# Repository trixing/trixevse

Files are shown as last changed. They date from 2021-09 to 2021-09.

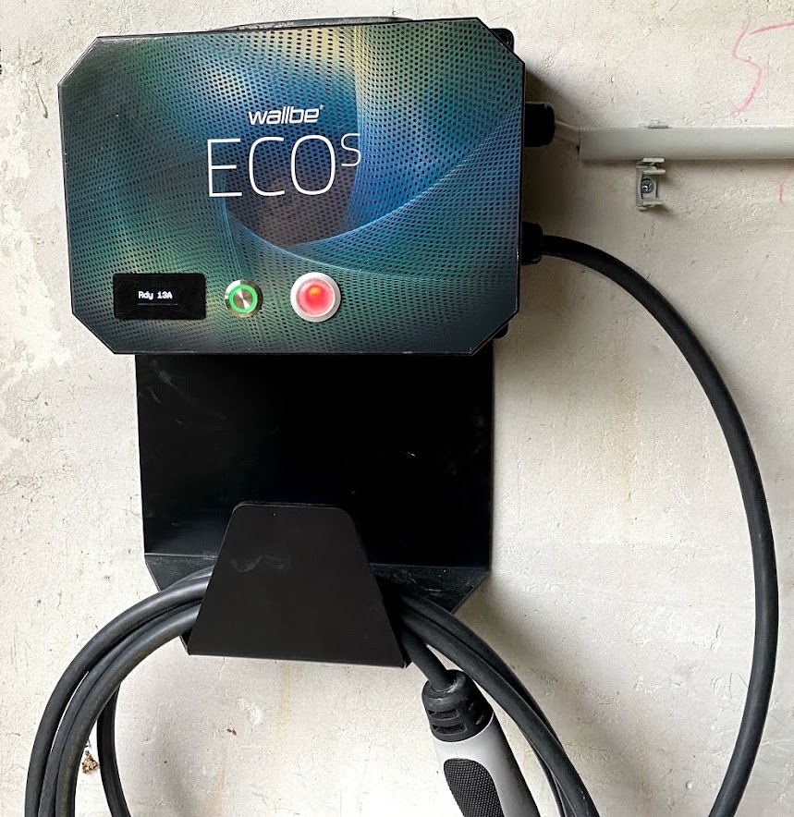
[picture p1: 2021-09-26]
pics/wallbox_wall.jpeg

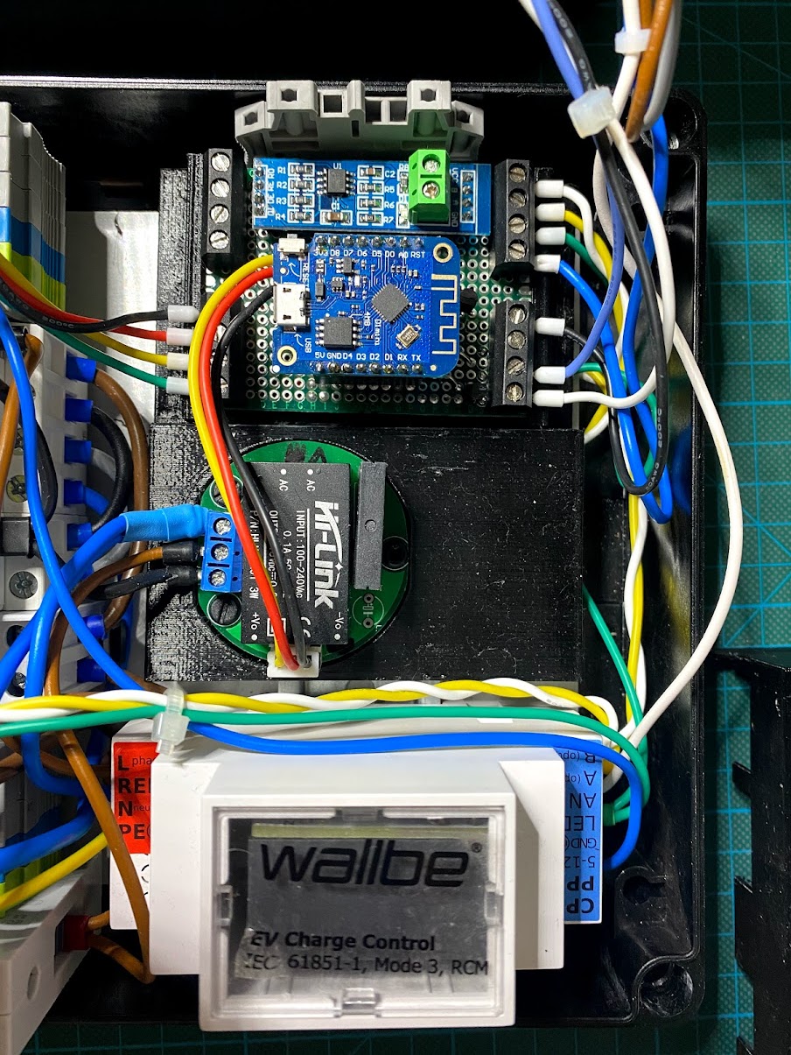
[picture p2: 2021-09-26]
pics/wallbox_open.jpeg

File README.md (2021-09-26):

# TrixEVSE - A custom electrical vehicle charging station

If your electrical vehicle charging station is broken and
the replacement part gets quoted north of the price of a new
wallbox this project might be for you.

This is taking a WallBe Eco 2.0s as a base, but most likely
works with a lot of other boxes which are built from off
the shelf parts and a Phoenix charge controller.

The documentation is work in progress.

## Features

-  mDNS listener at trixing-evse.local
-  Modbus interface (emulating an AC22 charger from Victron)
   See `https://github.com/victronenergy/dbus-modbus-client/blob/master/ev_charger.py`
-  HTTP JSON API `http://trixing-evse.local/j`

## Updating

Location of bin file on macOS:
```
find /var/folders/ -name '*.bin'
```

Run update via curl
```
curl -F "image=@trixing-evse-wifi.ino.bin" http://trixing-evse.local/update
```

## Software

-  Arduino 1.8.13
-  ArduinoJSON library
-  ModbusIP library
-  U8x8 library

## Parts

-  Broken Wallbox (I used a Wallbe Eco 2.0s)
-  Wemos D1 R1 Mini V3 ESP8266 based WiFi microcontroller
-  RS48 TTL converter based on MAX485
-  OLED I2C Display
   Makerhawk I2C SSD1306 128x32 3.3V/5V
-  Push Button
-  SDM120 Modbus Din Rail power meter
-  Din Rail Normally Open 2-phase relay
   e.g. Heschen CT1-25 2-pole Normally Open, 25A, 230V
-  EVSE DIN w/ RS485
   https://www.evse-wifi.de/produkt/evse-din-ladecontroller-rs485/

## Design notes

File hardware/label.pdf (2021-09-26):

ws | ge | gr | bl | sw | / | bl | ws
RS485 | | | GND | Button with LED | | | | Unused

# Trixing Wallbox, 11kW

Unused | | OLED Display | | 230 V, 0.4 A, 50 Hz
/ | / | / | / | | sw | rt | ge | gr | N | L | R2

Print @70% Scale on A4

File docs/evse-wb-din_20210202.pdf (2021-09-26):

# EVSE

## Wallbox, DIN, W16

## datasheet

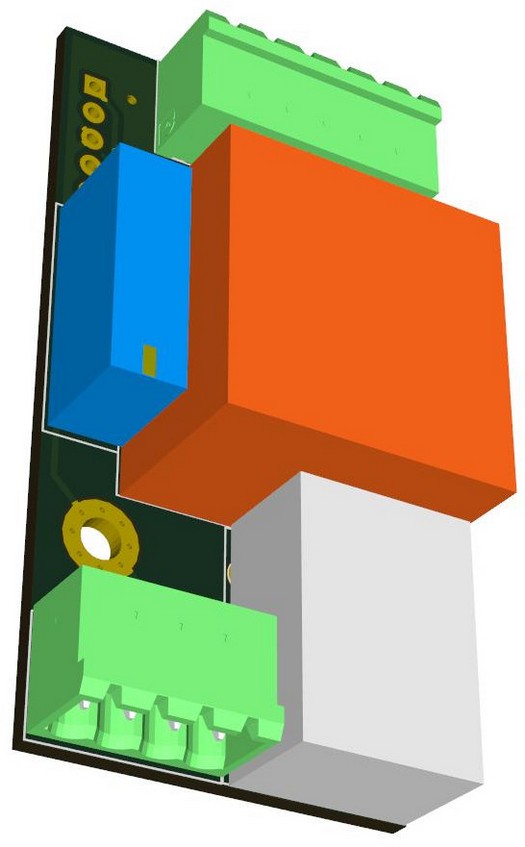
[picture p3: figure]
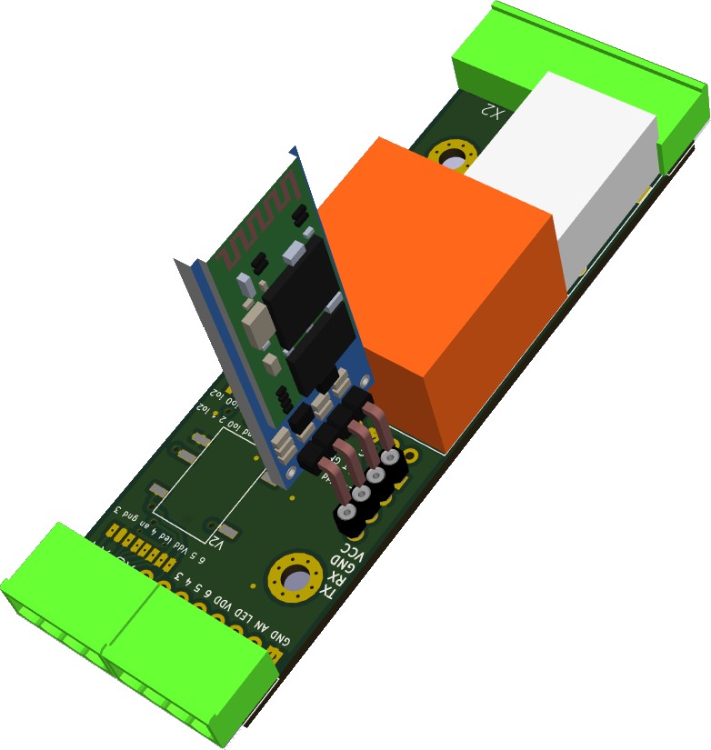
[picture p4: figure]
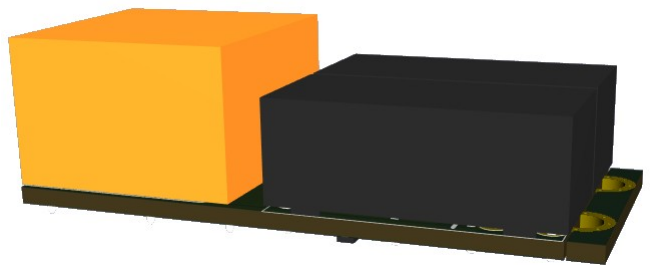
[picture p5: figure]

*) these are 3D generated models, real product can look differently and have different accessories

Last document update: February 2, 2021

## Table of Contents

## Introduction

EVSE stands for electric vehicle supply equipment. It is an element that supplies electric energy for the recharging of electric or plug-in vehicles.
Read me first
The EVSE board is supplied with default 32A settings (or 16A for EVSE W16). Please check the chapter “Customizations” for more information about further possibilities of changing maximum charging current. 220 Ohm RPP is included with the kit (EVSE WB). Theory of operation
Pilot signal duty cycle provided by EVSE defines maximum charging capacity. The car can define several states by pulling the pilot signal down to certain voltage levels (3V, 6V, 9V). Based on this feedback EVSE will trigger the relay for the vehicle to charge or evaluate the state as an error (electricity will not be provided to the output socket/connector).
For more information please check:
- http://en.wikipedia.org/wiki/IEC_62196
- http://en.wikipedia.org/wiki/SAE_J1772
- https://github.com/kortas87/simple-evse/wiki (https://code.google.com/p/simple-evse/)

### Resistance PP-PE (max cable throughput)

Resistance [ohm] | Current limit [A] | Wire cross-section [mm² ]
> 1500 * | 6 | --
1500 | 13 | 1.5
680 | 20 | 2.5
220 | 32 | 6
100 | 63 | 16
<100 ** | 80 | –
* | no resistor connected
** recommended ~50 Ohm

Compatibility
- Tesla Model S
- Nissan Leaf
- Mitsubishi iMiev (Peugeon iOn, Citroen cZero)
- Opel Ampera
- eGolf
- Mitsubishi Outlander PHEV
- Citroen Berlingo Electrique
- and others...

## General description EVSE WB, DIN, W16

### Parameters

Supply voltage | 90 – 265 VAC
Power consumption | <1W
AC/DC power | 1W or 3W
Operating temperature | -20 to 80 °C
Protection index | IP00
Onboard resistor for external LED | 1k
Vehicle compatibility | all vehicles according to IEC 62196
Connection options | HC06 bluetooth, UART-USB converter, wifi ESP8266, ethernet USR-TCP232/GSM, ...

All boards are based on the same software and hardware. Main differences between each other are described in this table:

EVSE | WB | DIN | W16 | W50
DIN rail mounting | yes with 3D printed case *) | yes | no | yes
PP detection | yes | yes | no | yes
power relay | no | no | yes 2x16A **) | yes 4x50A
3phase | yes | yes | no **) | yes
fits inside Type2 or Type1 | no | no | yes | no
wiring | easy | easy | medium | easy
supports vehicles | all | all | all | all
uart communication | yes | yes | yes | yes
in production | yes | yes | yes | late 2019
*) 3D data available on request
**) possible to change for 1x32A Panasonic relay with the same size or add another 2pcs 16A relay to get compact 11kW 3phase charger (wiring = difficult)

## EVSE WB - board description

### Parameters

Dimension (without connectors) | 60 x 30 x 25 mm
Mounting holes spacing | 30 x 20 mm
Relay | 5A 250V
Weight | 80 g
Order code | EVSE-WB
Options | HC06 bluetooth, UART-USB converter

EVSE WB board has 2 connectors. 4-pin X1 for high voltage side and 6-pin for signaling wires and control purposes. There is also PROG connector used for flashing new firmware (ICSP), additional communication and can be further used for adjusting EVSE current (see “Customizations” chapter).

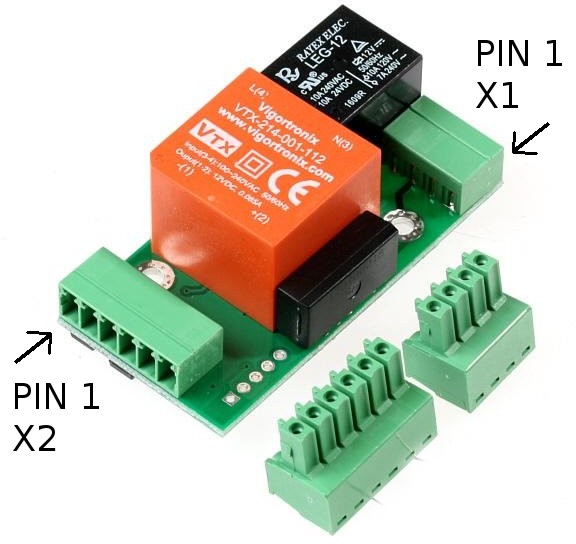
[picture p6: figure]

Picture 1: EVSE WB

### X1 connector = 4pins

pin | name | description
1: L | phase | 230V power supply for EVSE board and external
| neutral | contactor 2: N
3: PE | protection-earth | Ground reference
4: rel | relay output | This output drives coil of an external contactor Maximum allowed current is 3A.

### X2 connector = 6pins

pin | name | description
1: CP | control pilot | To vehicle connector
2: PP | proximity pilot | To vehicle connector
3: 5V | 5V power output | Used as a power supply for external components (max 40mA)
4: GND | ground | Ground reference
5: LED | external LED | Includes 1k resistor onboard, connects to LED anode against ground
6: AN | analog input | Used for button or current sensor input

### PROG connector = 5pin header

pin | name | description
1 | VPP | ICSP** / RFU* [marked by rectangle] from Jan 2018 bootloader enable pin
2 | VDD | 5 V
3 | GND | Ground
4 | DAT / TX | ICSP** / current boost / communication function
5 | CLK / RX | ICSP** / current limit / communication function
* reserved for future use
** firmware upgrade interface

## EVSE DIN - board description

(for reference only, was replaced by EVSE-DIN v2 during 2020, see details below)

### Parameters

Dimension (without connectors) | 86 x 29 x 25 mm
Mounting holes spacing | 54 x 18 mm
Relay | 5A 250V
Weight | 85 g
Order code | EVSE-DIN
Options | RS485 driver, HC06 bluetooth, UART converter, 3W AC/DC

For the minimum installation you can only wire 6pin X1 connector (required: L,N,REL,PE,PP,CP).

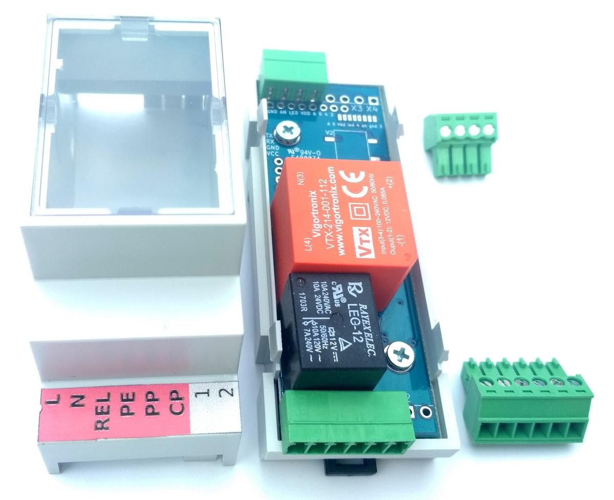
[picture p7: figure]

Picture 2: EVSE DIN

### X1 connector = 6pins

pin | name | description
1: L | phase | 230V power supply for EVSE board and external
| neutral | contactor 2: N
3: rel | relay output | This output drives coil of an external contactor Maximum allowed current is 3A
4: PE | protection-earth | Ground reference
5: PP | proximity pilot | To vehicle connector
6: CP | control pilot | To vehicle connector

### X2 connector = 2pins (OPTION)

pin | name | description
1:1 | | function defined by extension module
2:2 | | function defined by extension module

### X3 connector = 4pins

pin | name | description
1: 5V | 5V power output | Used as a power supply for external components (max 40mA)
2: LED | external LED | Includes 1k resistor onboard, connects to LED anode against ground
3: AN | analog input | Used for button or current sensor input
4: GND | ground | Ground reference

### X4 connector = 4pins (OPTION)

pin | name | description
1:3 | | function defined by extension module
2:4 | | function defined by extension module
3:5 | | function defined by extension module
4:6 | | function defined by extension module

### PROG connector = 5pin header (OPTION)

same function as EVSE WB

### UART connector = 4pin header (OPTION)

can be used for direct connection of HC06 (female header)

## EVSE DIN v2 - board description

Version 2020

### Parameters

Dimension (without connectors) | 86 x 29 x 25 mm
Fusing | Integrated fuse
Relay | 5A 250V
Weight | 85 g
Order code | EVSE-DIN
Terminals | Push terminals
Options | RS485 module, HC06 bluetooth, UART converter, locking module

For the minimum installation you can only wire 4pin X1 connector (required: L,N,REL,PE) + X2 (required CP)

Picture 3: EVSE DIN v2

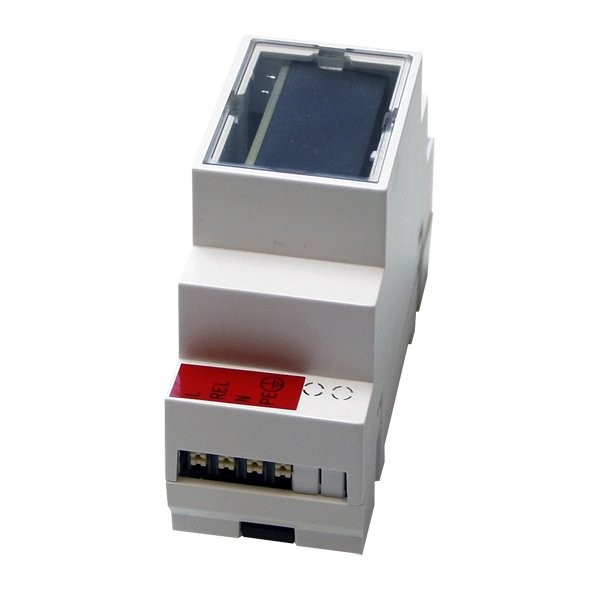
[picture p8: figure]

### X1 connector = 4pins (push terminals)

pin | name | description
1: L | phase | 230V power supply for EVSE board and external contactor
2: REL | relay output | This output drives coil of an external contactor maximum allowed current is <1A, fused
3: rel | neutral | 230V power supply for EVSE board and external contactor
4: PE | protection-earth | Ground reference

### X2 connector = 8pins (push terminals)

pin | name | description
1:CP | control pilot | To vehicle connector
2:PP | proximity pilot | To vehicle connector
3:12V | Power output | Possible to power external components. Default 12V, can be switched to 5V by onboard resistor jumper X7 (max 100mA)
4:GND | Ground reference | PE
5:LED | external LED | Includes 1k resistor onboard, connects to LED anode against ground
6:AN | analog input | Used for button or current sensor input
7:A | | function defined by extension module
8:B | | function defined by extension module

### PROG connector = 5pin header

same function as EVSE WB, part of the X3 header

### UART connector = 4pin header

can be used for direct connection of HC06 (female header), part of the X3 header

## EVSE W16 - board description

### Parameters

Dimension rev2 | 59 (55) x 26 x 22 mm
Dimension rev3 | 58 x 25 x 20 mm
Relay (default) | 2x16A 250V
Relay option 32A | 1x32A
Weight | Approx. 50 g
Order code | EVSE-W16 (2x16A relay) EVSE-W16_32A (1x32A relay)
Options | HC06 bluetooth, USB-UART converter

EVSE-W16 is the smallest board and also includes power relays for 16A. It can be considered as a successor of the original Simple EVSE, but with improved CP driver to support all vehicles, new software and AC/DC + relay integration. Solderable terminals instead of plugs keep it smaller. It can be mounted in many kinds of small boxes including Type1 or Type2 female connectors.
EVSE-W16 rev3 (May 2020) is upgraded version with following advantages:
- better surge rating and optimized component layout
- integrated fuse and inrush current limiter
- option for 32A relay (one phase type1/type2 ~7kW charger)

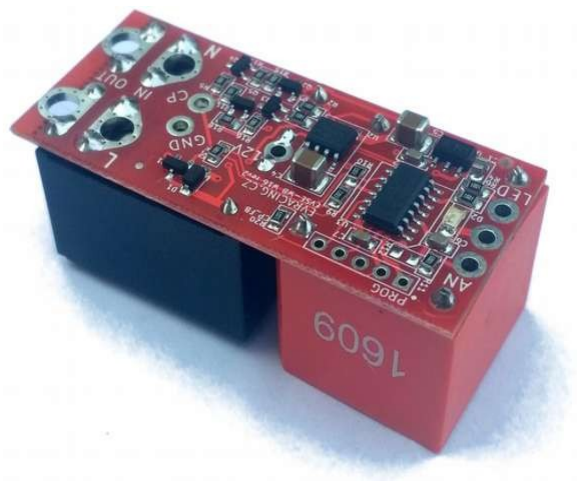
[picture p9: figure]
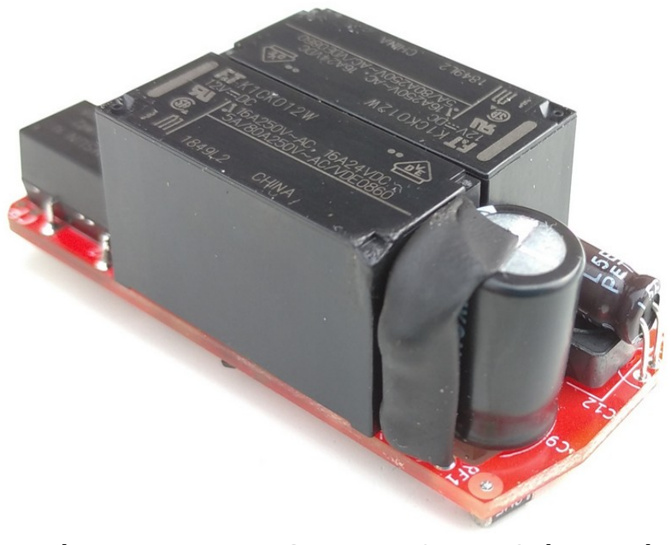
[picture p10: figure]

Picture 4: EVSE W16 rev2 board | Picture 5: EVSE W16 rev3 board

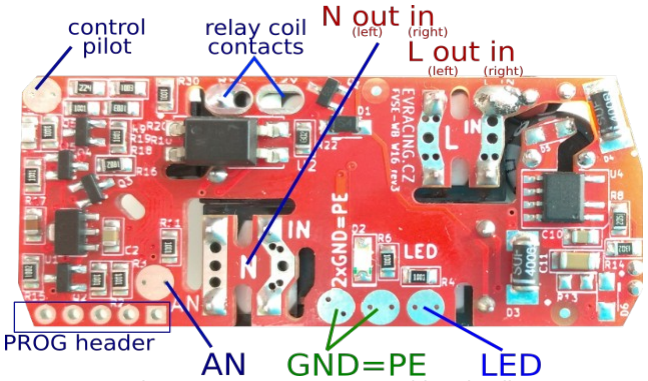
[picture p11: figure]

Picture 6: EVSE W16 rev3 wiring details

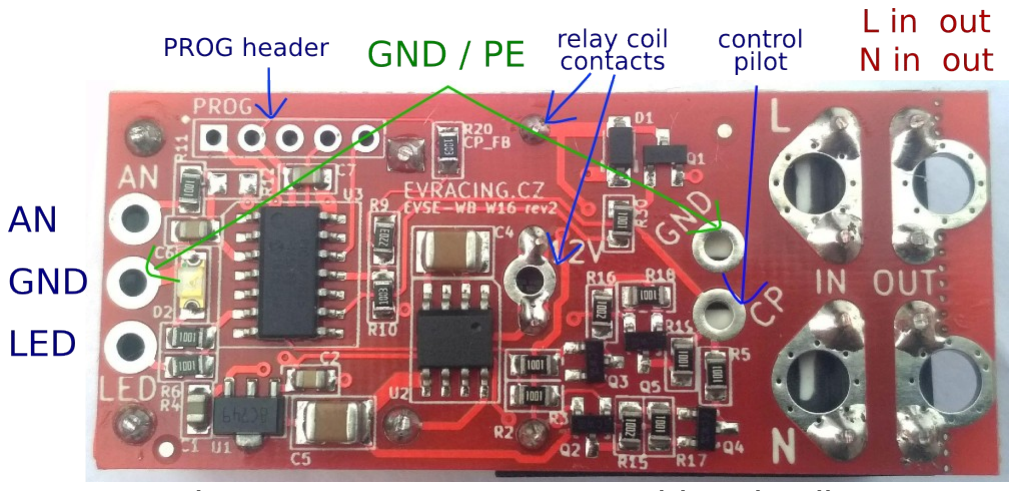
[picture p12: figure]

Picture 7: EVSE W16 rev2 wiring details

### pins overview

pin | name | description
L in | phase | 230V power supply for EVSE board + power input
N in | neutral
L out | phase | switched power output for the EV connector
N out | neutral
PE | protection-earth | = GND
CP | control pilot | To vehicle connector (Type1 or Type2)
LED | external LED | Includes 1k resistor onboard, connects to LED anode against ground
AN | analog input | Used for button or current sensor input
GND | ground | Ground reference (+ second GND between AN and LED), this is also PE reference
12V, - | relay coil contacts | can be used for adding relays for 3phase charger

### PROG connector = 5pin header (OPTION)

same function as EVSE WB

## Customizations

Current limitation A – using PROG pin 5
Check the table for details of how you can set the maximum current. This settings will override PIN 4 settings.
PROG connector | connection | current limit
pin5 > 4.5 V | open (internal pull-up only) | 32 A [default]
2.5 V < pin5 < 4.5 V | 100-200k* resistor to GND | 25 A
0.2 V < pin5 < 2.5 V | ~3-20k* resistor to GND | 16 A
pin5 < 0.2 V | tied to GND | 10 A
* resistor value may differ since internal pull-up has no defined value from production (~50k supposed), in most cases 100k for 25A and 5k for 16A is recommended

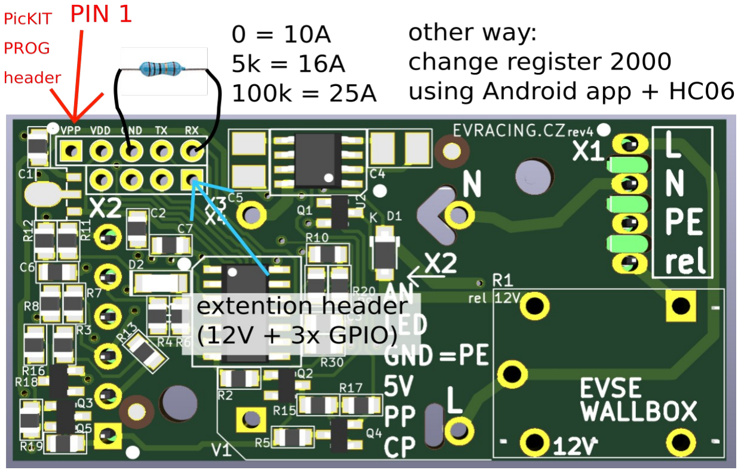
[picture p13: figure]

Current limitation B – using PROG pin 4
Check the table for details of how you can set the maximum current.
PROG connector | connection | current limit
pin4 > 4.5 V | open (internal pull-up only) | 32 A [default]
2.5 V < pin4 < 4.5 V | 100-200k* resistor to GND | 48 A
0.2 V < pin4 < 2.5 V | ~3-20k* resistor to GND | 63 A
pin4 < 0.2 V | tied to GND | 80 A
* resistor value may differ since internal pull-up has no defined value from production (~50k supposed), in most cases 5k for 63A and 100k for 48A is recommended

Picture 8: PROG header location on EVSE-WB board

Precise current setting with Analog Input
Press and hold button connected to Analog input AN of for a few seconds until LED starts to blink rapidly. Then count LED blinks which correspond to number of ampers. Please note that this limit will be set until you reboot the EVSE (make a power cycle). Button is connected the way that it pulls the signal down to ground (level <1V).

Current limitation based on PV production
We recommend to use any kind of control system (smart home PLC, Beaglebone with RS485 and SDM630 electricity meter, SDS micro...) and control the EVSE current continuously either by voltage input AN, via data communication (UART/RS485), or simply in 2 or more steps by relay outputs (EVSE is off, EVSE current low, EVSE current high). Each system is different as well as customer needs.

## Application examples

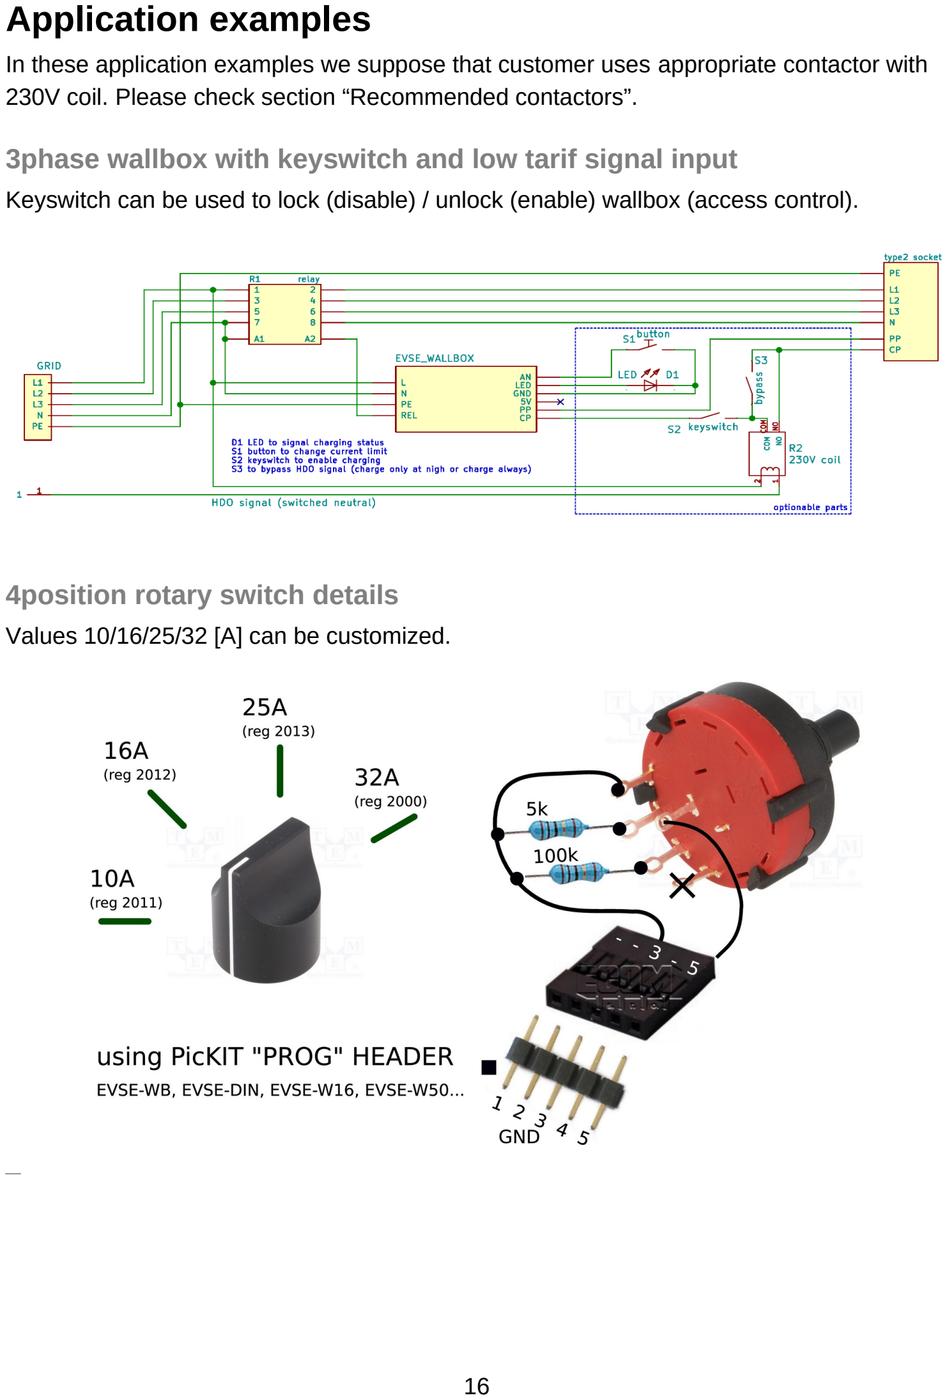
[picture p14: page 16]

In these application examples we suppose that customer uses appropriate contactor with 230V coil. Please check section “Recommended contactors”.

3phase wallbox with keyswitch and low tarif signal input
Keyswitch can be used to lock (disable) / unlock (enable) wallbox (access control).

4position rotary switch details Values 10/16/25/32 [A] can be customized.

_

3phase wallbox including a cable and plug
In this example we make 3 phase Wallbox using DSIEC-2E cable. PWM duty will be limited by the size of RPP (refer to the Theory of operation chapter). If you do not connect any RPP current will be limited to only 6A. If your EVSE includes a cable which is fixed then you can hard-wire RPP resistor for cable's nominal value.

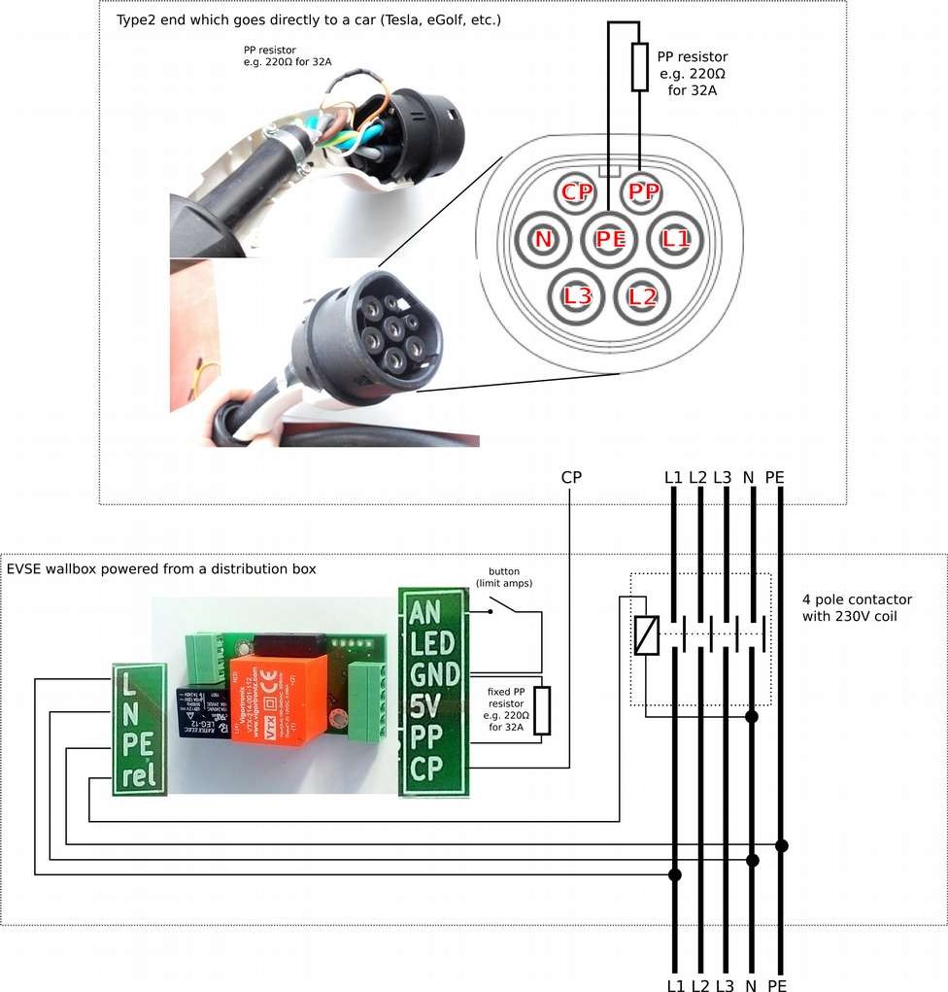
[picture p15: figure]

Picture 9: EVSE WB type2 fixed cable

32A EVSE with connector J1772
With EVSE Wallbox board you can quickly build a charging station for your Nissan Leaf 6.6kW or any other vehicle equipped with J1772 plug.

Optional Analog Input connection:
The internal J1772 connection allows to use S1 proximity button as an auxiliary button for EVSE. With the help of this button you can easily change charging current with the smallest step of 1A (see Features -Precise current setting).

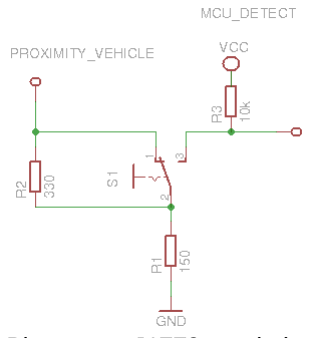
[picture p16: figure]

Picture 10: J1772 proximity button connection detail

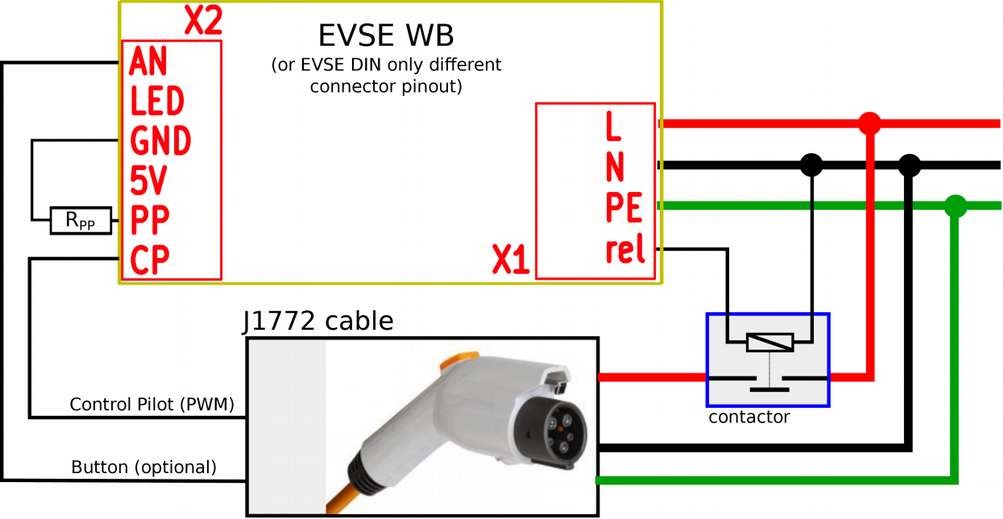
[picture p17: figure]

Picture 11: J1772 connector - signal and power wires

Recommended contactors
You should use relays / contactors equipped with 230V coil and connect them directly to the board connector X1. Here are some examples which relays can be used. The most common one (4pole contactor 25A) can be easily obtained in local electrical accessories shop (Conrad, K&V Elektro...)
- 3-phase, maximum current 20A (e.g. Tesla 11 kW):
Noark Ex9CH25 40, Elko VS420
- 3-phase, maximum current 40A (e.g. Tesla 16.5 / 22 kW, ZOE 22 kW): Elko VS440, Eaton Z-SCH 230V/25-40
- 1-phase, maximum current 16-20A (e.g. Peugeot iOn 3 kW, Tesla 3-4kW): Eaton Z-R230/S
- 1-phase, maximum current 40A (e.g. Nissan Leaf 6.6 kW):
RELPOL R40N
or use normal 4-pole contactor

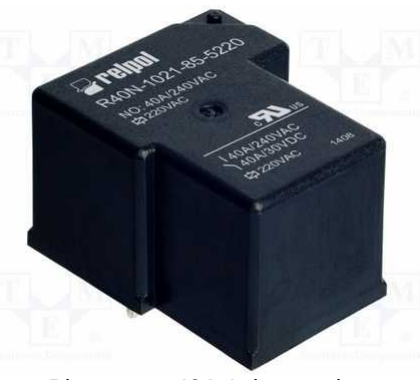
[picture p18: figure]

Using external 12V relay

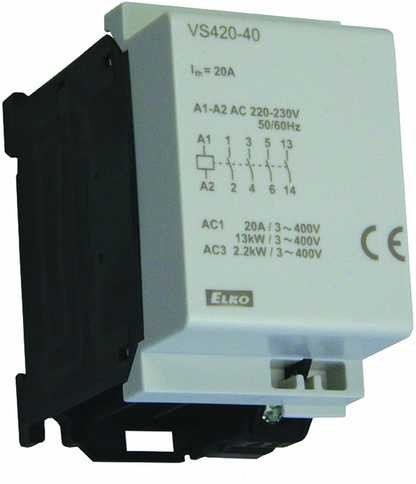
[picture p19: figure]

In some cases it would be possible to use another 12V coil relay (maximum 0.8W coil consumption), however this approach requires desoldering of the original relay and is recommended only to advanced users. Automotive relays can handle sufficient currents however their voltage rating is not high enough.
Pins marked by pink are connected to a 12V relay coil:

Picture 13: 40A 1phase relay

Picture 12: 20A 3phase relay

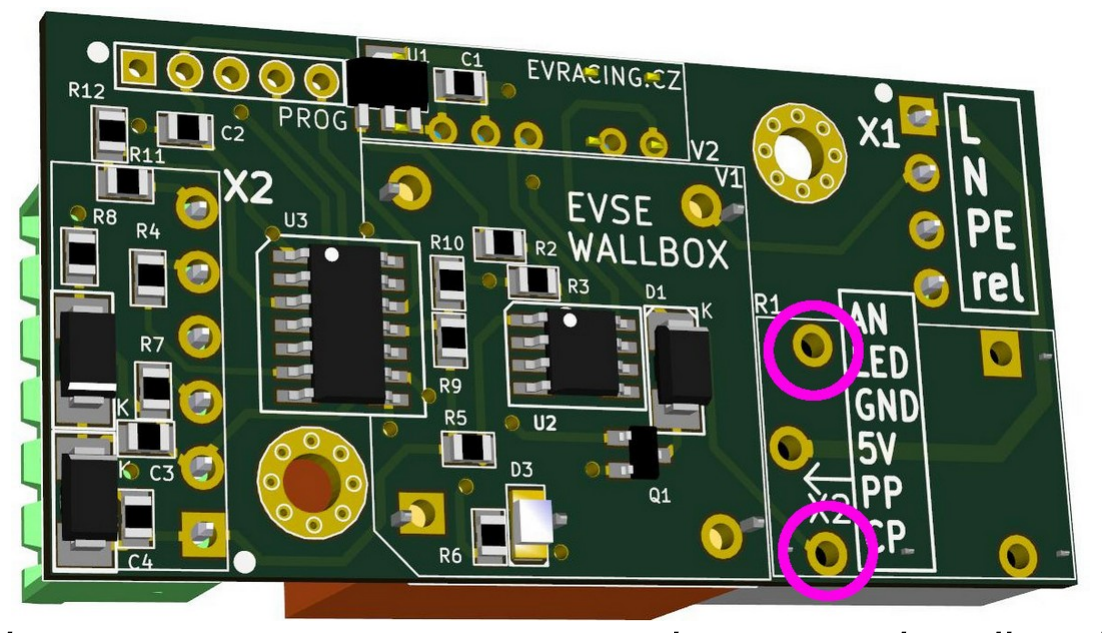
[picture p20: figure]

Continuous EVSE current regulation using a pot (e.g. 6-32A)
Use AN as EVSE voltage input and connect a potentiometer wiper. The other two terminals are to be connected to GND and 5V. Minimum 6A and maximum 32A can be adjusted in registers as needed.

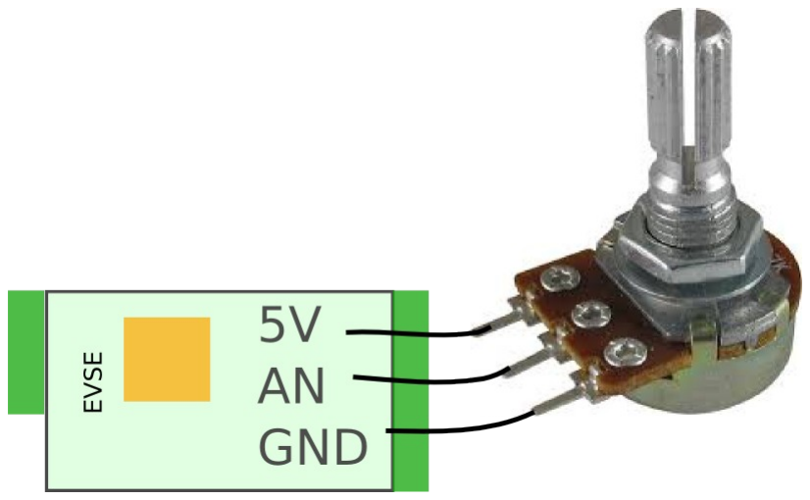
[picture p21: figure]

- set 2003 = 0 analog input current regulation
- set 2000 = 32A maximum current (AN = 5V)
- set 2002 = 6A minimum current (AN = 0V)
See the register table for more details. If you do not know how to change register values, please check “Advanced configuration” chapter.

0 - 10V configuration
Add a 1k resistor R12. R11 is also 1k and it will create a divider 1:1. Please note that this setup is recommended to use only with I/O modules having 0-10V analog output galvanically isolated.

Picture 14: EVSE WB - connecting 12V relay directly

Cable selection guide
rubber cables suitable for electric vehicles (type H07RN-F 450/750V)
type | diameter [mm] | current [A] | weight [kg/m] | application
5G6 + 0,75 | 18-22 | 38 | 0.7 | Type2 female 3phase charger, Type2
| 16-20 | 30 | 0.5 | male to Type2 female extension cable 5G4 + 0.75
5G2.5 + 0.75 | 13-17 | 20 | 0.4
4G6 | 16-20 | 37 | 0.6 | Type1 1phase charger, Type2 male to Type1 extension cable
3G6 | 14-18 | 40 | 0.4 | Type1 or Type2 1phase charger with EVSE built into the connector *)

*) other variants: 3x2.5mm 1phase, 5x2.5mm 3phase

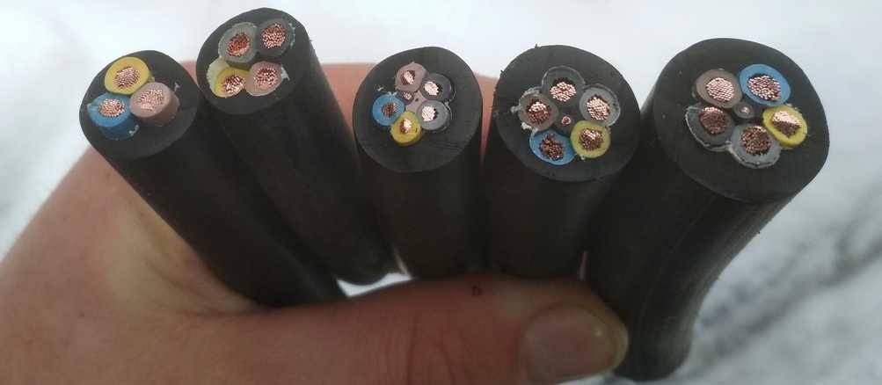
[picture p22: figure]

Picture 15: 3G6, 4G6, 5G2.5+0.75, 5G4+0.75, 5G6+0.75

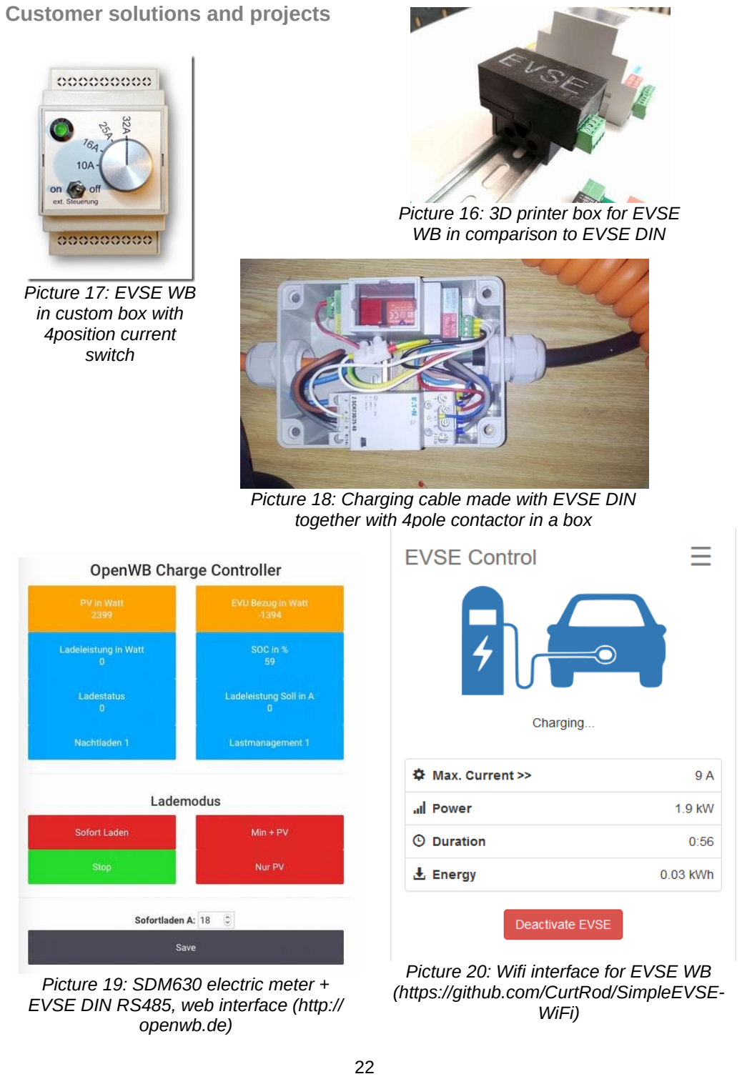
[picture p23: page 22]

Customer solutions and projects

Picture 17: EVSE WB
in custom box with
4position current
switch

Picture 18: Charging cable made with EVSE DIN together with 4pole contactor in a box

Picture 16: 3D printer box for EVSE WB in comparison to EVSE DIN

Picture 20: Wifi interface for EVSE WB (https://github.com/CurtRod/SimpleEVSE-WiFi)

Picture 19: SDM630 electric meter + EVSE DIN RS485, web interface (http://openwb.de)

## FAQ

1) How many PP resistors do I need?
As described in more detail above in the schematic (page 17), there must be one resistor in Type2 female (car side) and other resistor connected to an EVSE. Both are usually part of the extension cable Typ2 female (car side) to Type2 male (EVSE side). When using a fixed cable (not possible to disconnect from the EVSE) then the size of EVSE PP resistor can be “hardcoded” (modbus versions only, see register 2007 below) or a resistor of a fixed size have to be connected (usually 220 ohm for 32A cable).
2) EVSE does not work (config problem)
Make sure that the EVSE is not turned off (2005 configuration register). If the board does not respond at all, make sure the the UART parameters are correct (9600 baudrate, RX/TX+GND wired correctly). Did not the Modbus address change by accident (reg. 2001)?
Any kind of software / firmware / settings problem can be solved using a PicKIT and reprogramming the board from scratch using MPLAB IPE (do not forget to erase the chip too!). PicKIT 4 can be bought on Farnell (https://uk.farnell.com/search?st=pickit%204). EVSE firmware is ready for download from this link: http://evracing.cz/evse/evse-wallbox/fw_pickit/ .
Parameters and options:
- chip name is PIC16F1825
- “power target circuit from tool” (use 2-2.5V)
- “use high voltage program mode entry”
- pin1 (Vpp) is always marked (both on Pickit and the board too)
- if “power target circuit from tool” does not work, power the board externally
- when everything is ready, select HEX file “Browse” and click “Program”
- after successful programming you will see “Programming complete” in log window
3) LED indication explained
Using the pin LED you can directly connect LED to indicate EVSE status. The output includes 1k resistor. External LED has the same indication function as on-board LED.

LED | State description
| Normal operation:
1x fast + pause | pilot signal is steady +12V, no vehicle connected (can be customized – always ON)
2x fast + pause | PWM signal is generated, vehicle is present
1x long + pause | vehicle requested power, contactor is ON
20x fast in 0.5s | enter or leave current setting mode
1x each 0.3s | current setting mode – one more amper set
| Error states (no charging):
3x fast + pause | EVSE is disabled in software (FW >= 6)
4x fast + pause | Charging with ventilation is disabled (FW >= 13)
5x fast + pause | Pilot signal check failed (FW >= 11)
6x fast + pause | Residual current check failure (FW >= 16)
4) How to keep current settings after grid failure?
- see “advanced configuration” and enable communication (if necessary), see NOTE#1
- see HC06 bluetooth module + Android app
- set 2004 = 1 to save current set by button OR
- set 2000 = “desired amp value” to keep this maximum current every time

## Advanced configuration

Beginning January 2018 all boards can be configured by MODBUS. By default MODBUS interface is disabled and old functions of PROG pins are kept. However you can enable it by grounding PIN4 and PIN5 of PROG connector while powering the board up please see NOTE#1 instead.
Physical layer is not galvanically isolated UART (0-5V) or optionable isolated RS485 EVSE DIN only.
The default device ID is 1 (can be changed in register 2001).
Some values can be then read or written over MODBUS protocol. PROG pin header is used for this purpose with following pinout:
PROG connector | connection
pin3 | GND
pin4 | TX
pin5 | RX

This feature is useful for further development and testing with EVSE Wallbox board and can be also a great way to interface other devices such as Raspberry PI, Ethernet UART bridges (e.g. WIZnet or USR serial-to-ethernet boards), various WiFi modules etc.

HC06 bluetooth module + Android app
Preferred way is to use HC06 Bluetooth converter and Android application developed for this purpose. By default the communication is disabled (see NOTE#1 below register table), because the original analog functions of RX,TX pins are kept (for changing current by resistors).
You can download and install the app from here (*.apk extension): http://evracing.cz/evse/evse-wallbox/
HC06 is connected to PROG connector.
1. power up the board, HC06 should start blinking
2. pair your Android device with the adapter (default pin 1234)
3. open the EVSE app and choose the paired bluetooth adapter in its settings
4. hit connect button and wait for connection
5. read & write registers you need

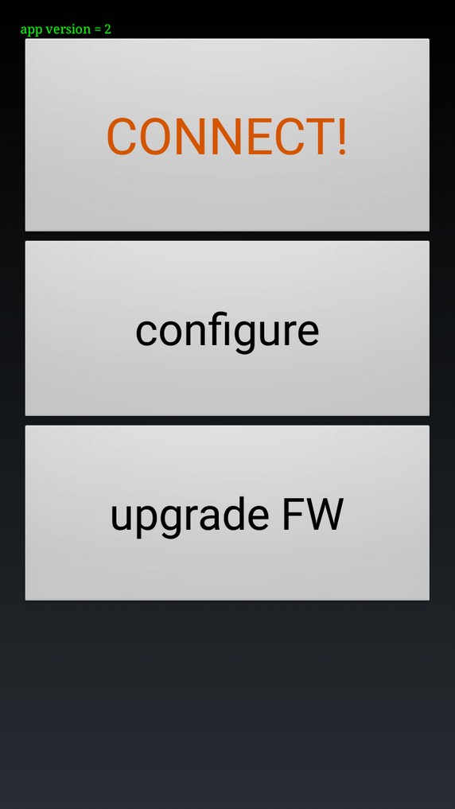
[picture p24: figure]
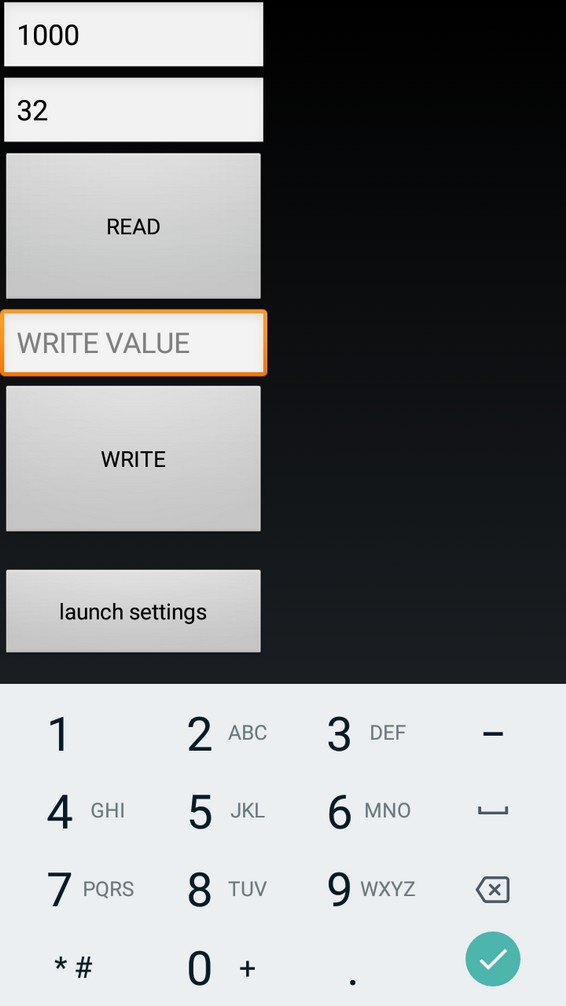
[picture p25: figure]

Flashing new firmware

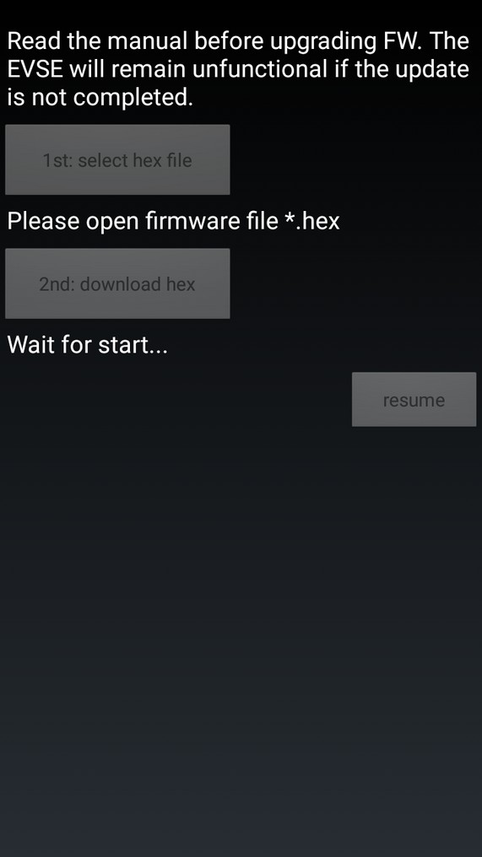
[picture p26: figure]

Flashing new firmware using Android phone is supported (with bluetooth adapter) on all EVSE DIN devices and on EVSE Wallbox devices only with “modbus firmware”. In order to flash new version of firmware bootloader mode must be enabled (last bit of the register 2005 - see the below).

Bootloader mode
If bootloader mode is activated the LED is solid on or off and it toggles when there is active communication. Bootloader mode can be turned off by changing the configuration register or it happens automatically after successful flashing of new firmware or there is a timeout of approximately 4 minutes.
When bootloader mode is activated, modbus slave address is set to 1.
The other way to enter bootloader mode is to keep analog input down when the device is booting (before powering on) for about 12 seconds (CHECK: or some more complicated way to prevent accidental bootloader turn on? CONCLUSION: if divider 1:1 used for AN => colision, result: this option disabled)
Bootloader change with board having initial revision 10: bootloader can be enabled by pulling MCLR (pin 1 PROG header) down for at least 12 seconds. This is needed for the case that software upgrade fails and there is no possibility to enable bootloader by changing the register.

Troubleshooting
If the download of a new firmware was not completed then you need to try it again, otherwise the board will not function properly. Last chance to fix badly programmed board is using PICKIT programmer (you can order PicKIT 4 on Farnell to get it fast).

How to determine firmware version?
If you power up the EVSE board and the LED is on for about 2 - 3 seconds you have Modbus firmware onboard and it is disabled. You can enable it this way NOTE#1. Firmware revision can be then read from register 1005.

Analog input control
Charging current can be changed based on analog input AN voltage (when register 2003 = 0). Minimum value is set in register 2002 and maximum in register 2000. Default supported range is 0 - 5V. Analog input is referenced to GND and is not isolated
Charging current (IPWM) for the vehicle is calculated:

IPWM = UAN / 5 * IMAX

Where UAN is the voltage measured at the input AN and IMAX is actual maximum current. Default is 32A, however it can be adjusted by settings or “current boost” / ”current limit” feature or change in configuration register.
If the resulting current is smaller than 6A then the EVSE state will change to “pilot steady 12V” and vehicle stops charing. Minimum current can be also adjusted in the register.

## Register table

Register address | R/W | def ault | Description
1000 | R/W | | Actual configured amps value (from reg 2002 to 80A)
1001 | R | | Actual amps value output
1002 | R | | Vehicle state: 1: ready 2: EV is present 3: charging 4: charging with ventilation 5: failure (e.g. diode check, RCD failure)
1003 | R | | 6 / 13 / 20 / 32 / 63 / 80 A Maximum current limitation according to a cable based on PP resistor detection
1004 | R/W | | bit0: turn off charging now bit1: run selftest and RCD test procedure (approx 30s) bit2: clear RCD error bit3 - bit15: not used
1005 | R | | Firmware revision
1006 | R | | EVSE state 1: steady 12V 2: PWM is being generated (only if 1000 >= 6) 3: OFF, steady 12V
1007 | R | | EVSE status and fails bit0: relay on/off bit1: diode check fail bit2: vent required fail bit3: waiting for pilot release (error recovery delay) bit4: RCD check error bit5: bit6-bit15: reserved
1008 | R | | Error timeout if > 0 then waiting for automatic clear
1009 | R | | Selftest timeout if > 0 then waiting for a selftest to complete
1010 | R | | reserved
2000 | R/W | 32 | Default amps value after boot (max 80A, min 6A)

Register address | R/W | def ault | Description
2001 | R/W | 0 | Function of PROG PIN 4 + 5, slave address (default 0: current limit or boost functions available) 0: analog inputs enabled > 0: MODBUS communication enabled This value also means the slave address.
2002 | R/W | 5 | Minimum amps value, allowed 0 - 13 if set to 0 the EVSE will completely stop charging during analog input mode (2003 = 0) and AN = 0V
2003 | R/W | 1 | Analog input config: 0: analog input current regulation, input 0 - 5V corresponds to the range: minimum amps --> default amps note that there is a weak pullup resistor enabled for this input (no input connected --> 5V) 1: each blink 1 amp step (default), starts from 0 2: each blink 2 amps step, starts from 0 3: each blink 3 amps step, starts from 0 ..... 10: each blink 10 amps step, starts from 0 11: mapping table: registers 2010 - 2017 1x blink = value from 2010 2x blink = value from 2011 ...
2004 | R/W | 0 | Amps settings after power on (applies only to a changes made by the button), whether to save amps settings to eeprom each time it changes or not 0 - do not save amps value (default) 1 - save amps value to register 2000 every time it changes

Register
address
| R/W | def ault | Description
2005 | R/W | 1 | bit0: Enable button for current change (no sense when 2003 = 0) 0: disabled 1: enabled (default) bit1: Stop charging when button pressed 0: disabled (default) 1: enabled charging will automatically start after you manually unplug and plug the cable to the vehicle bit2: Pilot ready state LED 0: blinks once (default) 1: is always ON bit3: enable charging on vehicle status D (ventilation required) 0: vehicle status D charging is disabled 1: vehicle status D charging is enabled (default) bit4: enable RCD feedback on MCLR pin (pin 4) 0: disabled, no RCD connected (default) 1: enabled bit5: auto clear RCD error 0: disabled (default, power cycle needed) 1: enabled (clear RCD error after <30s min timeout) bit6: (rev16 and later) 0: AN internal pull-up enabled (default) 1: AN internal pull-up disabled bit7-12: reserved bit13: disable EVSE after charge (write 8192) bit14: disable EVSE (write 16384) bit15: enable bootloader mode (write 32768) NOTE: if both bit0 and bit1 are enabled then “interrupt charging” will have higher priority, when charging
2006 | R/W | 0 | RFU: Current sharing mode is active (two or more EVSEs connected to a single breaker) 0 - charging current is half of the default current amps > 0: this amps value will be used
2007 | R/W | 0 | PP detection 0: PP detection enabled (default) value > 0: detection disabled, fixed PP limit entered [A]
2008 | R/W | | reserved
2009 | R | | Bootloader firmware revision
2010 | R/W | 6 | Amps value 1
2011 | R/W | 10 | Amps value 2
2012 | R/W | 16 | Amps value 3
2013 | R/W | 25 | Amps value 4

Register address | R/W | def ault | Description
2014 | R/W | 32 | Amps value 5
2015 | R/W | 48 | Amps value 6
2016 | R/W | 63 | Amps value 7
2017 | R/W | 80 | Amps value 8
Register addresses are in decimal format!
NOTE#1: By default MODBUS is NOT enabled, so the original analog input switches can be used (current limit and current boost functions). MODBUS can be enabled by pulling AN input down to GND while booting (= when you power the device up) at least 5 times within 3 seconds seconds (button activated). This will change register 2001 to the value 1, but it will not save the value permanently. Value will be saved after first successful R/W operation over MODBUS (register number >=2000).
NOTE#2: You can restore default settings of all registers by saving a value 65535 to the register 2010
NOTE#3: Only functions 03 (Read Holding Registers) and 16 (Preset Multiple Registers) are implemented. For more details please check: http://www.simplymodbus.ca/FAQ.htm RFU: reserved for future use
EVSE selftest:
1) turn on +12V (0 seconds)
2) turn on PWM generation, 5th second
3) enable 220R pp resistor (max 32A, 50% duty cycle), 10th second
4) turn on contactor (15th second)
5) RCD test procedure (if configured, 20th second, performs 500ms pulse on TEST-IN)
6) selftest finished after 30 seconds
Selftest counter (reg 1009) | Relay out | RCD test out | PP 220ohm | Action
300 | off | off | off | Steady +12V CP signal
250 | off | off | off | PWM 1kHz start, default duty cycle
200 | off | off | ON | PWM duty cycle change to 50%
150 | ON | off | ON | Relay activation
100-95 | ON | ON | ON | Test output RCD enabled ~500ms
0 | off | off | off | Steady +12V CP signal

NOTE: if equipped with RCD sensor, the test must finish with RCD error (LED blinks six times). RCD error must be cleared manually or by timeout (depending on config)

## Firmware updates

2020-06-25 revision 17:
- stricter CP signal check (pilot low decision level, shorted diode)
2020-04-27 revision 16:
- added RCD feedback support for EVSE-WBDIN (e.g. Bender RCMB121 and others)
- added configuration bit for AN pullup (can be disabled)
2020-02-15 revision 15:
- added minimum pilot_high condition (fix for Metrel A 1532 – status E/F test) 2019-09-01 revision 13:
- possible to change LED behavior in pilot steady state
- diode check fail increased error recovery delay
- EVSE status vent / without vent
2019-04-26 revision 12:
- RX buffer limit fix (mainly for RS485 systems)
2018-12-10 revision 11:
- improved CP signal check (implements status E), requires feedback resistor 100k (rev3 board R20, rev2 board R13, DIN version R21)
- if you do not upgrade feedback resistor, do not use firmware 11+
2018-10-30 revision 10:
- fix evse status register 1002 initial value (probably caused problems in OpenWB)
- modbus timeout set to 5 steps
2018-08-28 revision 9:
- combined code for EVSE DIN 485 and EVSE WB (but 2 different hex files)
- uart communication fix (RX overflow error check)
- weak pullup disabled for PP detection pin
- modbus timeout set to 3 steps
2018-02-06 bootloader v3:
- fix: removed reconfiguration from bootloader code (causing rewriting reg 2002) 2017-11-18 bootloader v2:
- added possibility to turn bootloader on by hardware pin 1 (Vpp/MCLR)
2017-11-18 Androi app v2:
- fixed .hex file parser (firmware upgrade), always use latest app version for firmware flashing!
2017-10-31 revision 8:
- added “disable EVSE after charge” bit (register 2005)
- fixed issue with voltage AN input - now follows minimum amps and does not turn off

2017-06-23 revision 7:
- interrupt routine rewritten (modbus communication)
- correct vehicle status update, if pwm is not being generated
- modbus timeout set to 20 steps
2017-06-07 revision 6:
- new configuration bits, register 2005 (disable EVSE, interrupt charging, change current)
- error code signalization
2017-05-03 revision 5:
- fixed current limit based on cable PP resistor (and analog pin input)
2017-04-26 revision 4:
- fixed amps value from AI (e.g. for max 32A reached only 31A and 5V input)
- fixed minimum amps value (was not taken into account)
2017-04-21 revision 3:
- added bootloader (Android application)
- fixed bug with analog input not working while modbus enabled
- added control register 1004
2017-04-13 revision 2:
- changeable slave address in reg 2001
- stop charging button function reg 2005 (no timeout, but wait for unplug & plug), bitfield introduced for more possible options
- added register 1005 (firmware revision number)
2017-02-17 revision 1:
- initial version

## Communication examples

Connection parameters: speed 9600, bytesize 8, stop bit 1, no parity, byte order Motorola.

Read holding registers example
01 03 03 E8 00 02 44 7B (request)
bytes | description
01 | The slave address (always 01 unless changed by customer)
03 | Function code (03 is for read holding registers function)
03 E8 | The data address of the first register to read
00 02 | The total number of registers requested.
44 7B | CRC-16 Modbus (cyclic redundancy check)

01 03 04 00 20 00 20 FA 21 (answer)

bytes | description
01 | The slave address (always 01)
03 | Function code (03 is for read holding registers function)
04 | The number of data bytes to follow (2 registers x 2 bytes each = 4)
00 20 | The contents of register 1000 (32A)
00 20 | The contents of register 1001 (32A)
FA 21 | CRC-16 Modbus (cyclic redundancy check)
Reading the data out with Python (USB – serial adapter)
You can use almost any MODBUS master utility for Windows / Linux / Mac. For common users we recommend using QModBus (http://qmodbus.sourceforge.net/). There is also QModMaster (http://sourceforge.net/projects/qmodmaster/) utility, but there may be a problem with write multiple registers function (there is bug in the software which causes register shift) - so use it carefully.

Advanced users can use Python / pymodbus (https://github.com/bashwork/pymodbus) for further development or similar libraries.
In following example we read out first 7 registers

#!/usr/bin/python3

from pymodbus.client.sync import ModbusSerialClient
client = ModbusSerialClient(method = "rtu", port=”/dev/ttyUSB0, baudrate=9600, stopbits=1, bytesize=8, timeout=1)
rq = client.read_holding_registers(1000,7,unit=1)
print(rq.registers)

#Reading the data out with Python (USB – serial adapter)

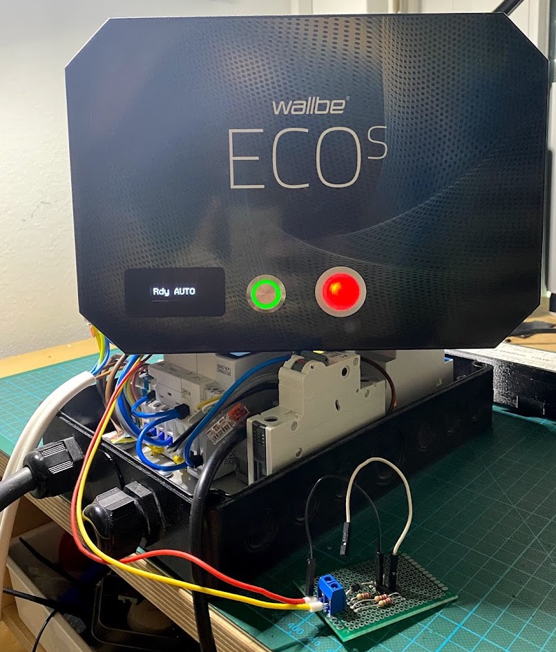
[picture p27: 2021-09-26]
pics/wallbox_front.jpeg

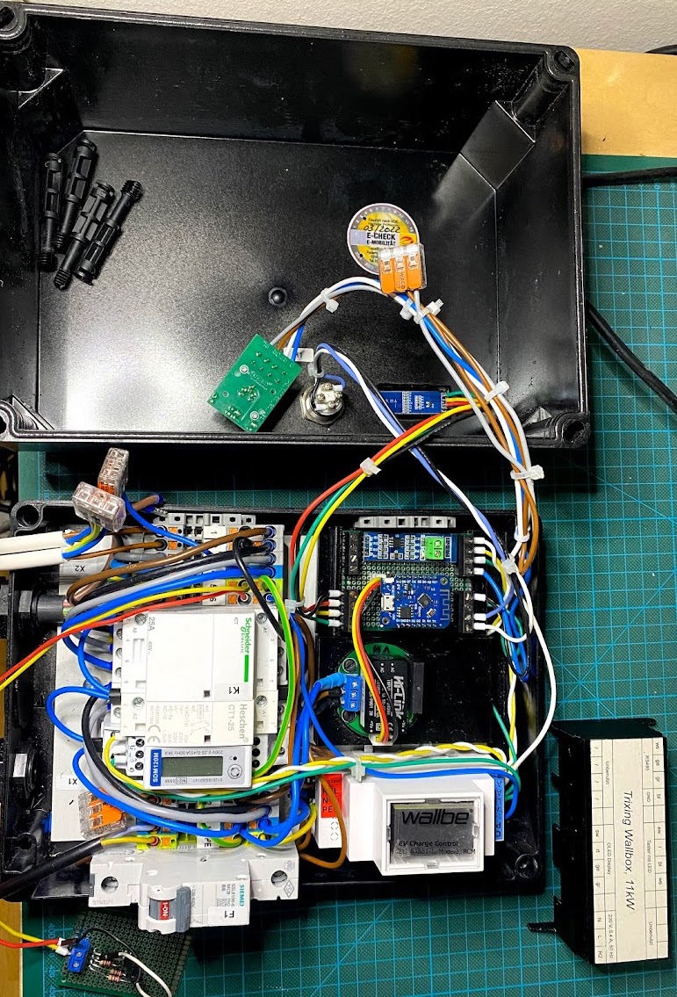
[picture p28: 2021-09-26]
pics/wallbox.jpeg

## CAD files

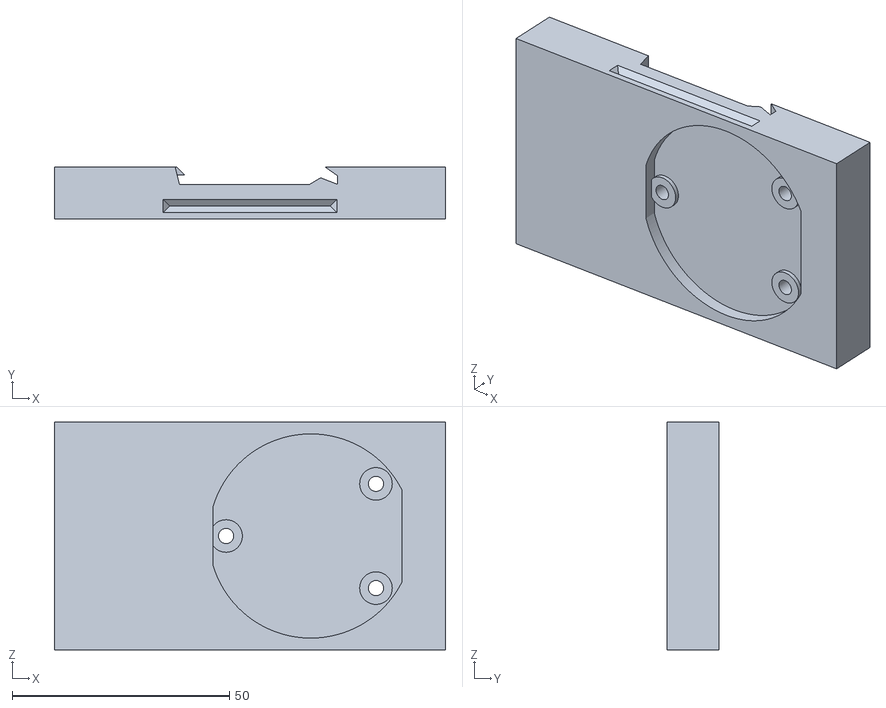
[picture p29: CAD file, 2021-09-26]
hardware/DinEvseRelais.stl
90.0 x 12.0 x 52.4

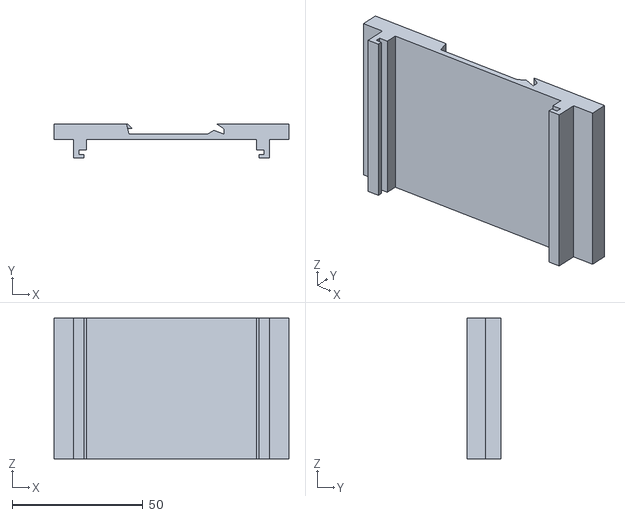
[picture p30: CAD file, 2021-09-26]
hardware/DinEvsePCB.stl
90.0 x 13.2 x 54.0

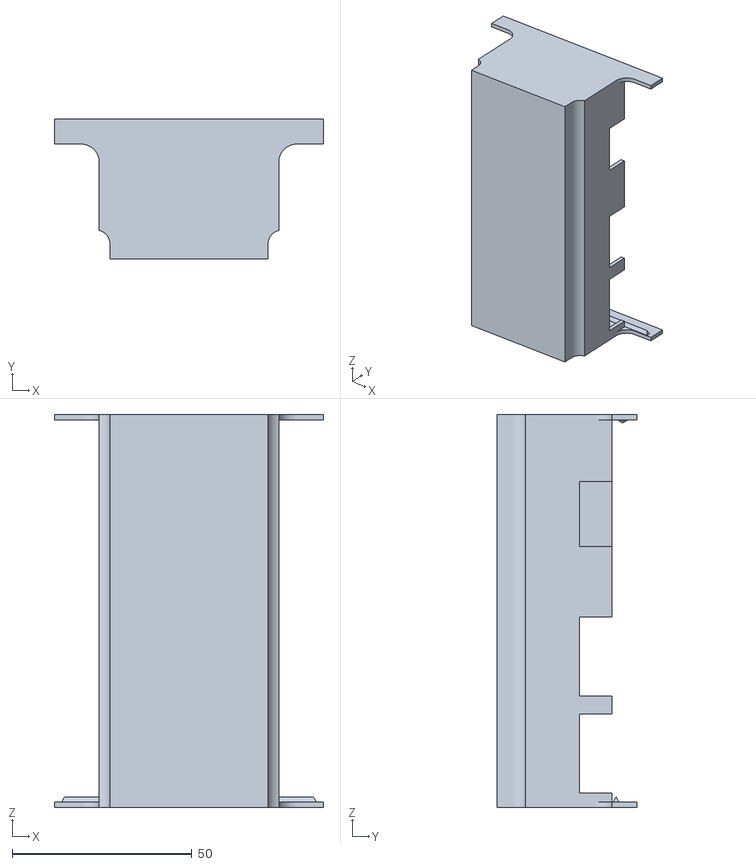
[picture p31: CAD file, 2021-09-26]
hardware/DinEvseLid.stl
75.0 x 39.0 x 109.4

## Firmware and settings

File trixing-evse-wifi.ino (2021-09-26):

/*
 * Target: Lolin D1 Mini
 */
#include "Arduino.h"
#include <SoftwareSerial.h>
#include <EEPROM.h>
#include <ESP8266WiFi.h>
#include <ESP8266WiFiMulti.h>
#include <ESP8266WebServer.h>
#include <ESP8266mDNS.h>
#include <ArduinoJson.h>
#include <ModbusIP_ESP8266.h>
#include <U8x8lib.h>
// #include <WiFiManager.h>
#include <ArduinoOTA.h>

#define VERSION "v2021.09.26"

#include "config.h"

#define CURRENT_LIMIT_BOOT 13
#define CURRENT_LIMIT_MIN 6
#define CURRENT_LIMIT_ONE 20
#define CURRENT_LIMIT_THREE 16
#define PP_CURRENT_LIMIT 20

#define THREE_PHASE_RELAY D8
#define THREE_PHASE_OFF 0
#define THREE_PHASE_ON 1
// Unused D5
// Unused A0

#define PUSH_BUTTON D6
#define PUSH_BUTTON_LED D7

#define RXPin        D4  // Serial Receive pin
#define TXPin        D3  // Serial Transmit pin

//RS485 control
#define SERIAL_COMMUNICATION_CONTROL_PIN D0 // Transmission set pin
#define RS485_TX_PIN_VALUE HIGH
#define RS485_RX_PIN_VALUE LOW

U8X8_SSD1306_128X32_UNIVISION_HW_I2C u8x8(/*reset=*/ U8X8_PIN_NONE, /* clock=*/ D1, /* data=*/ D2);

SoftwareSerial RS485Serial(RXPin, TXPin); // RX, TX
ESP8266WebServer server(80);
ModbusIP mb;


const byte evse_slave_id = 0x01;
const byte sdm_slave_id = 0x02;

int byteSend;

float sdm_voltage, sdm_current, sdm_power, sdm_energy, sdm_frequency,
      sdm_import_energy, sdm_export_energy, sdm_import_power, sdm_export_power;

unsigned long sdm_updated = 0, evse_updated = 0;

// 4: constant led, 8: on ventilation, 16: clear RCD error
// 16384: disable EVSE, 8192: disable EVSE after charge
// Register 2005
#define EVSE_CONFIG (4 | 8 | 16)
#define EVSE_CONFIG_DISABLE_CHARGING 16384

bool evse_charging = false, evse_vehicle_present = false, evse_charging_enabled = true;
unsigned int evse_config[10], evse_fw, evse_amp, evse_vehicle_state, evse_state, evse_status,
         evse_set_current = 0, evse_reg_charging = 0, evse_config_reg;
         
int request_evse_set_current = -1;
bool request_evse_stop_charging = false, request_evse_start_charging = false;

#define MODE_MANUAL_THREE 3
#define MODE_MANUAL 1
#define MODE_AUTO 2

int evse_mode = MODE_AUTO;
int request_evse_mode = -1;
int request_phases = -1;

unsigned long chargeStart = 0, chargeDuration = 0;
float chargeEnergy = 0, chargeEnergyStart = 0;
#define STATE_INIT 1
#define STATE_READY 2
#define STATE_CHARGING 3
#define STATE_ERROR 4
unsigned int state = STATE_INIT;

#define PHASE_UNKNOWN 0
#define PHASE_ONE 1
#define PHASE_THREE 3

unsigned int phase_state = PHASE_UNKNOWN;
String state_error, last_error;

// WiFiManager wifiManager;
ESP8266WiFiMulti wifiMulti;

#define CRC_SEED 0xFFFF  //initialization for CRC16
#define CRC_GP   0xA001  //generating polynomial

// #define MODBUS_DEBUG 1

void modbus_crc_single(unsigned char b, unsigned int* CRC)
{
  int carry, i ;

  CRC[0] ^= b & 0xFF;
  for (i = 0; i < 8; i++)
  {
    carry = CRC[0] & 0x0001;
    CRC[0] >>= 1;
    if (carry) CRC[0] ^= CRC_GP;
  }
}

void modbus_crc(unsigned char *b, int len, unsigned int *CRC) {
  *CRC = CRC_SEED;
  for (int i = 0; i < len; i++) {
    modbus_crc_single(b[i], CRC);
  }
}
/*
   01 The slave address (always 01)
  03 Function code (03 is for read holding registers function), 16 for write multiple registers
  04 The number of data bytes to follow (2 registers x 2 bytes each = 4)
  00 20 The contents of register 1000 (32A)
  00 20 The contents of register 1001 (32A)
  FA 21 CRC-16 Modbus (cyclic redundancy check)
*/

void byte2float(byte *data, float *res) {
  ((byte *)res)[0] = data[3];
  ((byte *)res)[1] = data[2];
  ((byte *)res)[2] = data[1];
  ((byte *)res)[3] = data[0];
}

void float2byte(float f, byte *data) {
  data[3] = ((byte *)&f)[0];
  data[2] = ((byte *)&f)[1];
  data[1] = ((byte *)&f)[2];
  data[0] = ((byte *)&f)[3];
}

// #define MODBUS_DEBUG 1

// read holding registers: modbus_send_command(0x01, 3, 1000, 10, 0);
// read input registers : modbus_send_command(0x01, 4, 1000, 10, 0);
// write multiple holding registers : modbus_send_command(0x01, 16, 1000, 10, int16);
int modbus_send_command(byte slave_id, byte function_code, int address, int count,
                        byte *payload, int payload_length,
                        byte *reply, int reply_length) {
  unsigned char data[10];
  unsigned int CRC;
  byte crc_offset = 6;
  int err = 0;

  data[0] = slave_id;
  data[1] = function_code; // read
  data[2] = address >> 8;
  data[3] = address & 0xff;
  data[4] = count >> 8;
  data[5] = count & 0xff;
  for (int i = 0; i < payload_length; i += 1) {
    data[6 + i] = payload[i];
    crc_offset += 1;
  }
  modbus_crc(data, crc_offset, &CRC);
  data[crc_offset + 1] = CRC >> 8;
  data[crc_offset] = CRC & 0xff;
#ifdef MODBUS_DEBUG
  Serial.print("TX ");
  for (int i = 0; i < (crc_offset + 2); i++) {
    Serial.print(data[i], HEX);
    Serial.print(" ");
  }
  Serial.println(".");
#endif
  // flush input queue
  while (RS485Serial.available()) {
    RS485Serial.read();
  }
  digitalWrite(SERIAL_COMMUNICATION_CONTROL_PIN, RS485_TX_PIN_VALUE);
  delay(1);
  RS485Serial.write(data, crc_offset + 2);
  RS485Serial.flush();
  digitalWrite(SERIAL_COMMUNICATION_CONTROL_PIN, RS485_RX_PIN_VALUE);
  delay(1);
  // read return value
  byte buf[4];
  unsigned int rx_crc = CRC_SEED;
  //delay(10);
  int rx_count = RS485Serial.readBytes(buf, 3);

  if (rx_count != 3) {
    err = 6;
    return err;
  }
  int rx_slave = buf[0];
  int rx_function = buf[1];
  int rx_len = buf[2];
  modbus_crc_single(buf[0], &rx_crc);
  modbus_crc_single(buf[1], &rx_crc);
  modbus_crc_single(buf[2], &rx_crc);

#ifdef MODBUS_DEBUG
  Serial.print("RX ");
  Serial.print(rx_slave);
  Serial.print(" F");
  Serial.print(rx_function);
  Serial.print(" L");
  Serial.print(rx_len);
  Serial.print(": ");
#endif

  if (rx_slave != slave_id) {
    err = 3;
  }
  if (rx_function != function_code) {
    err = 4;
  }

  for (int i = 0; i < rx_len; i += 1) {
    rx_count = RS485Serial.readBytes(buf, 1);
    if (rx_count == 1) {
#ifdef MODBUS_DEBUG
      Serial.print(buf[0], HEX);
      Serial.print(" ");
#endif
      modbus_crc_single(buf[0], &rx_crc);
      if (i < reply_length) {
        reply[i] = buf[0];
      }
    } else {
#ifdef MODBUS_DEBUG
      Serial.print("TO");
#endif
      err = 2;
      break;
    }
  }
  rx_count = RS485Serial.readBytes(buf, 2);
  if ((buf[0] != (rx_crc & 0xff)) || (buf[1] != (rx_crc >> 8))) {
    Serial.print("CRCerr ");
    Serial.print(buf[0], HEX);
    Serial.print(" ");
    Serial.print(buf[1], HEX);
    Serial.print(" vs. ");
    Serial.print(rx_crc, HEX);
    Serial.print(" ");
    err = 1;
  }
#ifdef MODBUS_DEBUG
  Serial.println(".");
#endif
  return err;
}

int modbus_handle_error(const char *fun, int address, int error) {
  if (error) {
    Serial.print("Modbus Error ");
    Serial.print(fun);
    Serial.print(" ");
    Serial.print(address);
    Serial.print(" ");
    Serial.println(error);
  }
  return error;
}
int modbus_read_input_float(byte slave_id, int address, float *res) {
  byte buf[4], tries = 0;
  int err = 0;
  while (tries < 3) {
    err = modbus_send_command(slave_id, 4, address, 2, NULL, 0, buf, 4);
    if (!err) break;
    tries++;
  }
  if (err) return modbus_handle_error("modbus_read_input_float", address, err);
  byte2float(buf, res);
  return 0;
}

int modbus_read_holding_int(byte slave_id, int address, unsigned int *res) {
  byte buf[4], tries = 0;
  int err = 0;
  while (tries < 3) {
    err = modbus_send_command(slave_id, 3, address, 2, NULL, 0, buf, 4);
    if (!err) break;
    tries++;
  }
  if (err) return modbus_handle_error("modbus_read_holding_int", address, err);
  *res = ((unsigned int)buf[0] << 8) + buf[1];
  return 0;
}

int modbus_read_holding_multi_int(byte slave_id, int address, unsigned int count, unsigned int *res) {
  byte buf[40], tries = 0;
  int err = 0;
  while (tries < 3) {
    err = modbus_send_command(slave_id, 3, address, count, NULL, 0, buf, 40);
    if (!err) break;
    tries++;
  }
  if (err) return modbus_handle_error("modbus_read_holding_multi_int", address, err);
  for (unsigned int i = 0; i < count; i++) {
    res[i] = ((unsigned int)buf[0 + 2 * i] << 8) + buf[1 + 2 * i];
  }
  return 0;
}

int modbus_read_holding_uint32(byte slave_id, int address, uint32_t *res) {
  byte buf[4];
  int err = modbus_send_command(slave_id, 3, address, 2, NULL, 0, buf, 4);
  if (err) return modbus_handle_error("modbus_read_holding_uint32", address, err);
  *res = ((uint32_t)buf[0] << 24) + ((uint32_t)buf[1] << 16) + ((uint32_t)buf[2] << 8) + buf[3];
  return 0;
}


int modbus_read_float(byte slave_id, int address, float *res) {
  byte buf[4];
  int err = modbus_send_command(slave_id, 3, address, 2, NULL, 0, buf, 4);
  if (err) return modbus_handle_error("modbus_read_float", address, err);
  byte2float(buf, res);
  return 0;
}

int modbus_write_float(byte slave_id, int address, float value) {
  byte buf[5];
  buf[0] = 4;
  float2byte(value, buf + 1);
  int err = modbus_send_command(slave_id, 16, address, 2, buf, 5, NULL, 0);
  if (err) return modbus_handle_error("modbus_write_float", address, err);
  return 0;
}


int modbus_write_int(byte slave_id, int address, unsigned int value) {
  byte buf[3], tries = 0;
  int err;
  buf[0] = 2;
  buf[1] = value >> 8;
  buf[2] = value & 0xff;
  while (tries < 3) {
    err = modbus_send_command(slave_id, 16, address, 2, buf, 3, NULL, 0);
    if (!err) break;
    tries++;
  }
  if (err) return modbus_handle_error("modbus_write_int", address, err);
  return 0;
}



#define REG_MODEL 5000
#define REG_SERIAL 5001
#define REG_FW 5007
#define REG_MODE 5009
#define REG_START_STOP 5010
#define REG_AC_L1P 5011
#define REG_AC_L2P 5012
#define REG_AC_L3P 5013
#define REG_AC_P 5014
#define REG_STATUS 5015
#define REG_SET_CURRENT 5016
#define REG_MAX_CURRENT 5017
#define REG_CURRENT 5018
#define REG_CHARGING_TIME 5019
#define REG_ENERGY_FORWARD 5021

uint16_t cbWrite(TRegister* reg, uint16_t val)  {
  if ((state == STATE_INIT) || (state == STATE_ERROR)) {
     return val;
  }
  if (reg->value == val) {
    return val;
  }
  Serial.print("Write. Reg RAW#: ");
  Serial.print(reg->address.address);
  Serial.print(" Old: ");
  Serial.print(reg->value);
  Serial.print(" New: ");
  Serial.println(val);
  switch (reg->address.address) {
    case REG_MODE:
      Serial.println("REG_MODE not implemented");
      break;
    case REG_START_STOP:
      if (val == 1) {
        if (!evse_charging)
          request_evse_start_charging = true;
      } else {
        if (evse_charging)
          request_evse_stop_charging = true;
      }
      break;
    case REG_SET_CURRENT:
      Serial.print("REG_SET_CURRENT to");
      Serial.println(val);
      request_evse_set_current = val;
      break;
  }
  return val;

}

bool cbConn(IPAddress ip) {
  /*
    Serial.print("Modbus connection: ");
    Serial.println(ip);
  */
  return true;
}

uint16_t cbEVSE(TRegister* reg, uint16_t val) {
  Serial.println("cbEVSE callback GET");
  unsigned int r = 0;
  int err = modbus_read_holding_int(evse_slave_id, reg->address.address, &r);
  if (err) {
    Serial.print("ERROR ");
    Serial.println(err);
  }
  return r;
}

uint16_t cbEVSESet(TRegister* reg, uint16_t val) {
  Serial.println("cbEVSE callback SET");
  int err = modbus_write_int(evse_slave_id, reg->address.address, val);
  if (err) {
    Serial.print("ERROR ");
    Serial.println(err);
  }
  return val;
}

void init_modbus() {
  // see https://github.com/victronenergy/dbus-modbus-client/blob/master/ev_charger.py, models
  mb.addHreg(REG_MODEL, 0xc024);
  for (int i = 0; i < 6; i++) {
    mb.addHreg(REG_SERIAL + i, 65);
  }
  mb.addHreg(REG_FW, 1);
  mb.addHreg(REG_FW + 1, 0);
  mb.addHreg(REG_MODE, 1); // 0 MANUAL or 1 for auto
  mb.onSetHreg(REG_MODE, cbWrite, 1);
  mb.addHreg(REG_START_STOP, 0); // or 1 for start
  mb.onSetHreg(REG_START_STOP, cbWrite, 1);
  mb.addHreg(REG_AC_L1P, 1);
  mb.addHreg(REG_AC_L2P, 1);
  mb.addHreg(REG_AC_L3P, 1);
  mb.addHreg(REG_AC_P, 1);

  mb.addHreg(REG_SET_CURRENT, 1);
  mb.onSetHreg(REG_SET_CURRENT, cbWrite, 1);
  mb.addHreg(REG_MAX_CURRENT, 1);
  mb.onSetHreg(REG_MAX_CURRENT, cbWrite, 1);
  mb.addHreg(REG_CURRENT, 10);
  mb.addHreg(REG_CHARGING_TIME, 0);
  mb.addHreg(REG_CHARGING_TIME + 1, 0);

  mb.addHreg(REG_ENERGY_FORWARD, 100);

  // Passthrough for debugging of EVSE
  for (int i = 1000; i < 1010; i++) {
    mb.onGetHreg(i, cbEVSE);
    mb.onSetHreg(i, cbEVSESet, 1);
  }
  for (int i = 2000; i < 2020; i++) {
    mb.onGetHreg(i, cbEVSE);
    mb.onSetHreg(i, cbEVSESet, 1);
  }
  updateModbus();
  mb.onConnect(cbConn);
  mb.server();
}
void updateModbus() {
  // https://github.com/victronenergy/dbus-modbus-client/blob/master/ev_charger.py
  unsigned int p = sdm_power;
  mb.Hreg(REG_MODE, 1);
  mb.Hreg(REG_AC_L1P, p);
  if (phase_state == PHASE_ONE) {
    mb.Hreg(REG_AC_L2P, 0);
    mb.Hreg(REG_AC_L3P, 0);
    mb.Hreg(REG_AC_P, p);
  } else {
    mb.Hreg(REG_AC_L2P, p);
    mb.Hreg(REG_AC_L3P, p);
    mb.Hreg(REG_AC_P, 3 * p);
  }
  /*
         DISCONNECTED    = 0
    CONNECTED       = 1
    CHARGING        = 2
    CHARGED         = 3
    WAIT_SUN        = 4
    WAIT_RFID       = 5
    WAIT_START      = 6
    LOW_SOC         = 7
    GND_ERROR       = 8
    WELD_CON        = 9
    CP_SHORTED      = 10
  */
  int mb_status = 0;
  if (evse_charging) {
    mb_status = 2;
  } else if (evse_vehicle_present) {
    mb_status = 1;
  }
  mb.Hreg(REG_STATUS, mb_status);

  mb.Hreg(REG_SET_CURRENT, evse_set_current);
  mb.Hreg(REG_MAX_CURRENT, PP_CURRENT_LIMIT);

  mb.Hreg(REG_CURRENT, evse_amp * 10);
  
  mb.Hreg(REG_CHARGING_TIME, chargeDuration);

  mb.Hreg(REG_ENERGY_FORWARD, (int)(chargeEnergy*100));


}

DynamicJsonDocument doc(1024);
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
void loop() {
  unsigned long now = millis();
  switch (state) {
    case STATE_INIT:
      if ((now - lastInitRetry) > 5000) {
        lastInitRetry = now;
        if (sdmInit()) {
          state_error = "SDM Init failed";
          state = STATE_ERROR;
          lastStateError = now;
          break;
        }
        if (evseInit()) {
          state_error = "EVSE Init failed";
          state = STATE_ERROR;
          lastStateError = now;
          break;
        }
        state_error = "";
        updateModbusData();
      } else {
        break;
      }
      Serial.println("Ready?");
      request_evse_mode = -1;
      state = STATE_READY;
    // Intentionally no break to fall through to charging check.
    case STATE_READY:
      if (evse_charging) {
        state = STATE_CHARGING;
        chargeStart = now;
        chargeDuration = 0;
        chargeEnergyStart = sdm_energy;
        chargeEnergy = 0;
        break;
      }
      if (request_evse_mode != -1) {
        modeTimeout = now + 2 * 60000; // 2 minutes
        if (!evse_charging_enabled) {
          request_evse_start_charging = true;
        } else if (evse_mode == MODE_AUTO) {
          evse_mode = MODE_MANUAL;
          request_evse_set_current = CURRENT_LIMIT_ONE;
        } else if (evse_mode == MODE_MANUAL) {
          evse_mode = MODE_MANUAL_THREE;
          request_evse_set_current = CURRENT_LIMIT_THREE;
        } else {
          evse_mode = MODE_AUTO;
          // 1 phase has a higher limit anyways than 3-phase
          // request_evse_set_current = CURRENT_LIMIT_BOOT;
          request_phases = PHASE_ONE;
          // digitalWrite(THREE_PHASE_RELAY, THREE_PHASE_OFF);
          // phase_state = PHASE_ONE;
        }

      }
      if ((now > modeTimeout) && (evse_mode != MODE_AUTO)) {
        evse_mode = MODE_AUTO;
        // We are not charging, so this is safe to do.
        request_evse_set_current = CURRENT_LIMIT_BOOT;
        request_phases = PHASE_ONE;
      }
      request_evse_mode = -1;
      break;
    case STATE_CHARGING:
      if (request_evse_mode != -1) {
        evse_stop_charging();
      }
      request_evse_mode = -1;
      if (!evse_charging) {
        // sane default after charging.
        state = STATE_READY;
        phase_state = PHASE_ONE;
        evse_mode = MODE_AUTO;
        // Do not reset current, if we go from 3 to 1 phase, the limit will be smaller anyways.
        // request_evse_set_current = CURRENT_LIMIT_BOOT;
        break;
      }
      if (chargeEnergyStart == 0) {
        chargeEnergyStart = sdm_energy;
      }
      chargeDuration = now - chargeStart;
      chargeEnergy = sdm_energy - chargeEnergyStart;
      if (phase_state == PHASE_THREE) {
        chargeEnergy *= 3;
        // We detected we are in the charging state, we consume power, that
        // means the relay is hold on by the "back-current" from the charging
        // phase.  Turn this off that in case of power interruption, we want
        // to fall back to PHASE_ONE state. (see above)
        if (evse_charging && (sdm_power > 5.0)) {
          digitalWrite(THREE_PHASE_RELAY, THREE_PHASE_OFF);
          // not setting phase_state to ONE until after charging is done (see above)
        }
      }
      break;
    case STATE_ERROR:
      if ((now - lastStateError) > 30000) {
        state = STATE_INIT;
      }
      request_evse_mode = -1;
      break;
    default:
      // should never happen(tm)
      state = STATE_ERROR;
      lastStateError = now;
      break;
  }

  if (((evse_mode == MODE_MANUAL_THREE) && (phase_state != PHASE_THREE)) || (request_phases == PHASE_THREE)) {
    evse_toggle_three_phases(PHASE_THREE);
  } else if (((evse_mode == MODE_MANUAL) && (phase_state != PHASE_ONE))  || (request_phases == PHASE_ONE)) {
    evse_toggle_three_phases(PHASE_ONE);
  }
  request_phases = -1;
  char tmp[10], tmp2[10];
  unsigned long  s = (now % 15000) / 5000;
  int phase_multiplier = 1;
  if (phase_state == PHASE_THREE) {
    phase_multiplier = 3;
  }
  switch (state) {
    case STATE_INIT:
      update_display("Init");
      break;
    case STATE_READY:
      if (evse_vehicle_present) {
        sprintf(tmp, "Veh");
      } else {
        sprintf(tmp, "Rdy");
      }
      if (!evse_charging_enabled) {
        sprintf(tmp2, "%s DIS", tmp);
      } else if (s == 0) {
        switch (evse_mode) {
          case MODE_AUTO:
            sprintf(tmp2, "%s AUTO", tmp);
            blink_mode("1");
            break;
          case MODE_MANUAL:
            sprintf(tmp2, "%s 1-PH", tmp);
            blink_mode("11110000");
            break;
          case MODE_MANUAL_THREE:
            sprintf(tmp2, "%s 3-PH", tmp);
            blink_mode("101010000");
            break;
        }
      } else {
        if (phase_state == PHASE_ONE) {
          sprintf(tmp2, "%s %dA", tmp, evse_set_current);
        } else if (phase_state == PHASE_THREE) {
          sprintf(tmp2, "%s 3x%d", tmp, evse_set_current);
        } else {
          sprintf(tmp2, "%s ?P?", tmp);
        }
      }
      update_display(tmp2);
      break;
    case STATE_CHARGING:


      switch (evse_mode) {
        case MODE_AUTO:
          sprintf(tmp2, "Chg %.0fkW", phase_multiplier * sdm_power / 1000);

          blink_mode("1");
          break;
        case MODE_MANUAL:
          sprintf(tmp2, "1ph %.0fkW", phase_multiplier * sdm_power / 1000);
          blink_mode("11110000");
          break;
        case MODE_MANUAL_THREE:
          sprintf(tmp2, "3ph %.0fkW", phase_multiplier * sdm_power / 1000);
          blink_mode("101010000");
          break;
      }

      if (s == 1) {
        sprintf(tmp2, "%.2fkWH", phase_multiplier * chargeEnergy);
      } else if (s == 2) {
        unsigned long duration = (now - chargeStart) / 1000;
        if (duration < 300) {
          sprintf(tmp2, "%ld sec", duration);
        } else if (duration < 3600) {
          sprintf(tmp2, "%ldm%lds", duration / 60, duration % 60);
        } else {
          unsigned long m = (duration % 3600) / 60;
          sprintf(tmp2, "%ldh%ldm", duration / 3600, m);
        }
      }

      update_display(tmp2);
      break;
    case STATE_ERROR:
      update_display(state_error.c_str());
      blink_mode("10"); // fast blink
      break;

  }

  if ((now - lastModbusUpdate) > 1000) {
    //Serial.print(".");
    if ((state != STATE_INIT) && (state != STATE_ERROR)) {
      updateModbusData();

    }
    updateModbus(); // update external (server modbus)
    lastModbusUpdate = now;
  }

  blink_manager();
  server.handleClient();
  mb.task();
  /*
  if (WiFi.status() == WL_CONNECTED) {
    if (wifi_manager_portal_active) {
      Serial.println("Wifi Connected, disable portal");
      wifiManager.stopWebPortal();
      start_webserver();
      wifi_manager_portal_active = false;
    }
  } else {
    // TODO add a timeout before starting the web portal.
    if (!wifi_manager_portal_active) {
      Serial.println("Wifi Disconnected, enable portal");
      wifiManager.startWebPortal();
      wifi_manager_portal_active = true;
    }
  }
  wifiManager.process();
  */
  ArduinoOTA.handle();
  MDNS.update();
  wifiMulti.run();
  yield();
}
